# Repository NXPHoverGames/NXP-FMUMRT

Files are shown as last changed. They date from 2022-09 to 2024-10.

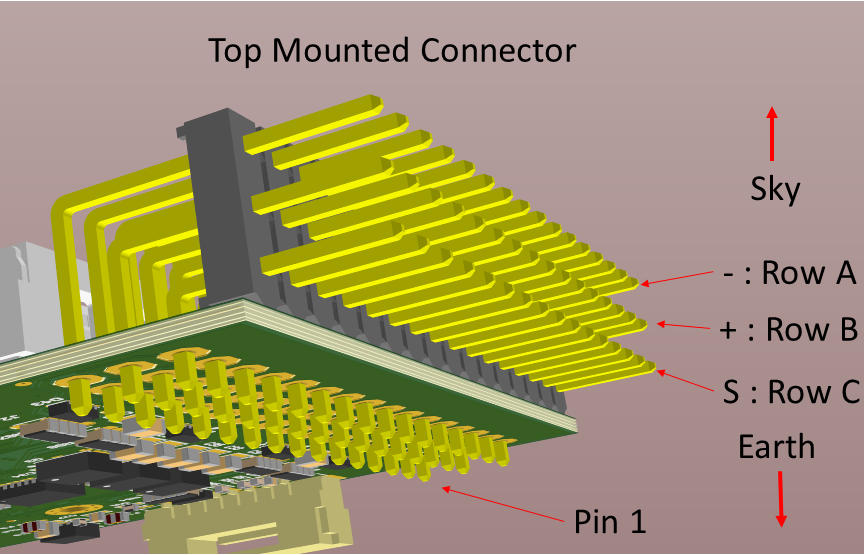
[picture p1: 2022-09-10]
RT-VxX_Carrier_Board/RC01/Project_fmuvxXbaseT1_RC01_20220511_1/3x16_Header.png

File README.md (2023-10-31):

# NXP-FMUMRT, MR-FMURT6, MR-VMU-RT117x
This is an open reference design for a Pixhawk V5X (i.MX RT1062) / V6X (i.MX RT117x) flight controller. 

Note1: For MR-FMURT6 based on NXP i.MX RT1062: This design is NOT being produced in volume, and we will produce MR-VMU-RT1176 using i.MX RT1176 MCU instead.
The RT1176 offers higher processing speed (Ghz) and additional UARTS as well as a dual core processor.
MR-FMURT6 It is still a valuable reference point for cost-optimzed design usign i.MX RT1062
Alternative software could also be used on this design such as Zephyr + Cognipilot.

Note2: MR-VMU-RT117x is being called a "VMU" or "Vehicle Management Unit" rather than "FMU" or "Flight Management Unit" since this is more inclusive 
of the many types of vehicles that can use a real time controller. 

Note3: The i.MX RT117x is currently contstrained on MR-VMU-RT117x by the Pixhawk Autopilot Bus (PAB) connector standard. 
The PAB standard was already revised to allow for extra PWM from the RT1176 and allows potential elimination of the IO co-processor that is on 
the VxX carrier board. Additionally there is a 3rd CAN port available.
(July/2023) - In the future look for a revised VxX7 carrier board which makes use of these new signals on the PAB.

Note4: Given the i.MX RT117x is currently contstrained on MR-VMU-RT117x, we will look in the future collaboration on a "chip down" design that takes advantage
of all the extra IP an peripherals such as the camera and vision pipeline that are currently unused on this chip.

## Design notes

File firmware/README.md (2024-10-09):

# Firmware for px4_fmu-v6xrt (i.MX RT117x)

**This info is aimed to be used for testers of the Pixhawk 6X-RT (Developer Edition)**

Hardware desccription on Manufacturers webpage - https://holybro.com/products/fmuv6x-rt-developer-edition
Documentation on PX4.io - https://docs.px4.io/main/en/flight_controller/pixhawk6x-rt.html

**IMPORTANT** if you are using the v6xrt FMUM on a development baseboard from NXP and like to use the T1 ethernet: 
Please make sure that you enable the T1 ethernet PHY - **TJA1103** - via **make px4_fmu-v6xrt menuconfig**. 
Ethernet PHY is in **Device Drivers** --> **Network Device/PHY Support** --> **Board PHY Selection (ETH0)** 

## Firmware sources
PX4 firmware for px4_fmu-v6xrt has been merged to PX4 main - https://github.com/PX4/PX4-Autopilot on Nov 15th 2023.
Please build from there.

## Issue reporting
Please report all issues found via https://github.com/PX4/PX4-Autopilot/issues/new/choose

## flashing the code
### with QGC
For flashing code with QGC stable release version v4.4.0 or later is needed  - https://docs.qgroundcontrol.com/master/en/qgc-user-guide/getting_started/download_and_install.html

### with PX4 developer toolchain based on own compiled code
1) Install PX4 developer toolchain according https://docs.px4.io/main/en/dev_setup/dev_env.html
2) Download PX4 Autopilot sourcecode - https://docs.px4.io/main/en/dev_setup/building_px4.html#download-the-px4-source-code
3) Move into PX4-Autopilot code directory
4) do **git pull --recurse-submodules**
5) optional: do **make distclean** if you had build already from this code directory before.
6) do **make px4_fmu-v6xrt_default upload** to build the PX4 FW image and flash via USB
7) connect Pixhawk v6X-RT via USB to flash the PX4 FW image

### updating the bootloader
For this a **SEGGER debug probe** HW is needed - https://www.segger.com/products/debug-trace-probes/
As well as the **SEGGER J-Link** SW - https://www.segger.com/downloads/jlink/
And the **Pixhawk Debug Adapter** - https://holybro.com/collections/flight-controller-accessories/products/pixhawk-debug-adapter

1) Move into PX4-Autopilot code directory with checked out pr-px4_fmu-v6xrt (see instruction above)
2) do **git pull --recurse-submodules**
3) do **make distclean**
4) do **make px4_fmu-v6xrt_bootloader** to build the PX4 bootloader
5) Connect the holybro pixhawk debug adapter, with SEGGER debug probe connected, to Pixhawk 6X-RT
6) Power the Pixhawk 6X-RT either via USB or POWERx connector.
7) Launch JlinkExe
8) Type connect
9) Select SWD and target is MIMXRT1176XXXA_M7
10) type reset and halt
11) Type loadbin /path/to/firmware/px4_fmu-v6xrt_bootloader.bin 0x30000000              # needed only in case of bootloader to be flashed
12) type reset and go

## Precompiled PX4 FW images

**IMPORTANT:** Support for px4_fmu-v6xrt has been merged to PX4 main on 15th of Nov 2023. Therefore we no longer provide precompiled images.
Please build the bootloader and PX4 FW according instruction above.

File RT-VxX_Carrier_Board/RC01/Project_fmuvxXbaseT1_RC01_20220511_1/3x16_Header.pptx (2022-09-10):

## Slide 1

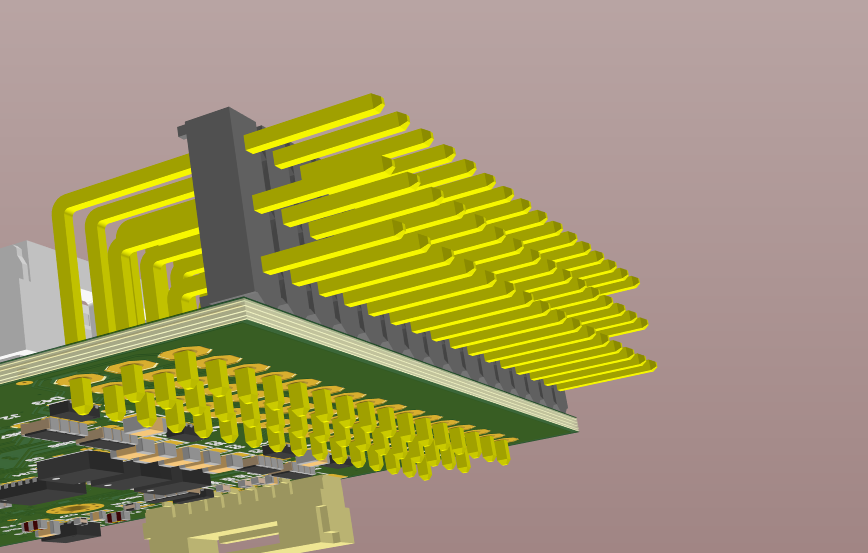
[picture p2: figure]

Top Mounted Connector

Sky

- : Row A

+ : Row B

S : Row C

Earth

Pin 1

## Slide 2

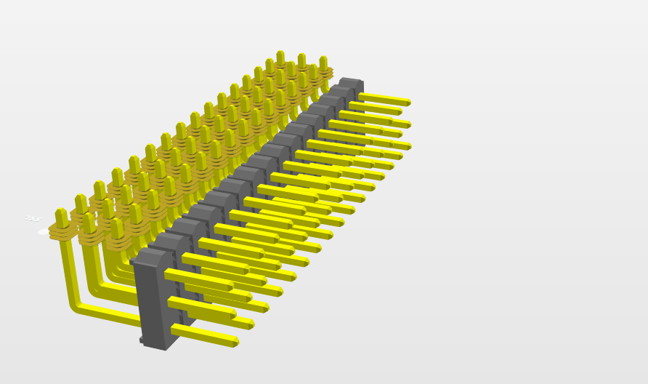
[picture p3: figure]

Bottom Mounted Connector

- : Row C

Pin 1

+ : Row B

S : Row A

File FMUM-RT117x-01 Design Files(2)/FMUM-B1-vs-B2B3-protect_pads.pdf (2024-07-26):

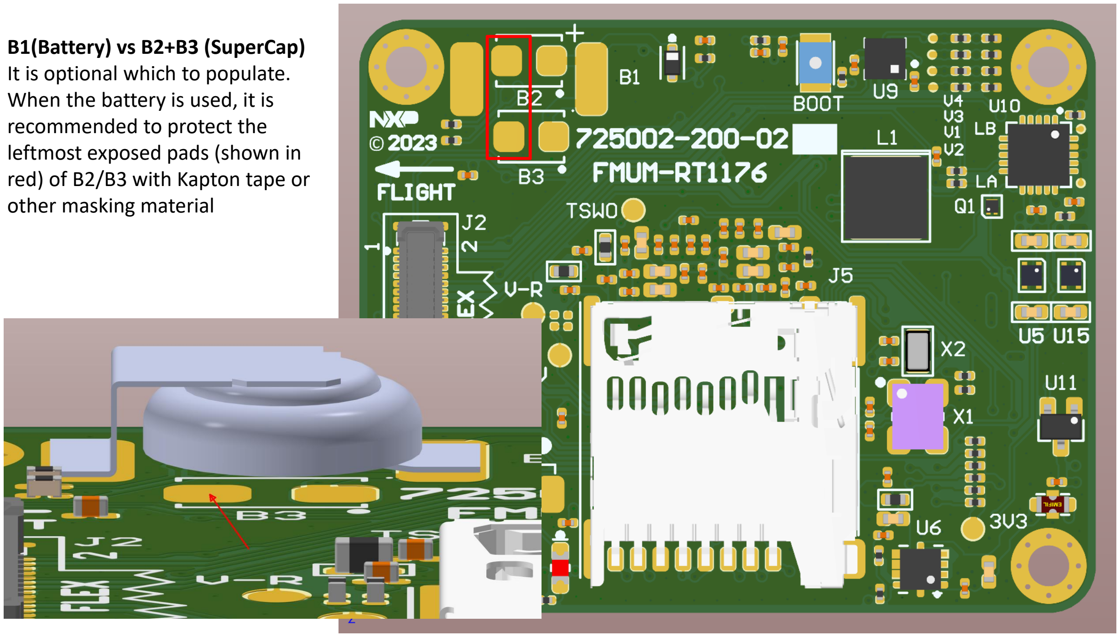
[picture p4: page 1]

B1(Battery) vs B2+B3 (SuperCap) It is optional which to populate. When the battery is used, it is recommended to protect the leftmost exposed pads (shown in red) of B2/B3 with Kapton tape or other masking material

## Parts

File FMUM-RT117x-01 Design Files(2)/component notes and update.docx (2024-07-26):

26/07/2024

Notes on components or FMUMRT1176 and Vxx-T1
1) MAX803SQ263T1G : As a replacement for MAX803SQ263T1G, I would suggest to use MIC803-26D3VC3 instead. This has the same specifications as the original. The suggested part is almost the same, but has a different threshold voltage.
https://www.digikey.nl/en/products/detail/microchip-technology/MIC803-26D3VC3-TR/2566974

2) 3225SMD-24.000MHZ crystal has already been replaced in the last update by Kyocera CX3225SB24000D0FLJCC.
https://www.digikey.nl/en/products/detail/kyocera-avx/CX3225SB24000D0FLJCC/6123307

# 3) The BMP388 barometer on the FMUM has been replaced already by BMP390 in the latest update. https://www.digikey.nl/en/products/detail/bosch-sensortec/BMP390/16164575 4) B1, MS621R II27E – Lithium battery may be difficult to source. The design allows for supercap alternative 2x CPH3225A

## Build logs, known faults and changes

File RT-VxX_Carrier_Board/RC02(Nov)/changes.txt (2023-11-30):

11/30/2023 iafg

-	Resistor values changed which give the id of the board
-	Corrected the reverse pinning on the DSM connector
-	Physically Moved the NFC cable connector that was blocking the SDCARD
- Re-Connected “loose” signals for the GPS arming and led. (the nets got accidentally disconnected when the IO processor was removed)

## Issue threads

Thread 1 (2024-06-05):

No internal MAG sensor?

napdynamite, 2024-06-05:
Hi,

I have been trying to find the internal MAG sensor on FMURT6 BOM but I guess this design does not have internal MAG sensor. Or is the design pending?

igalloway, 2024-06-05:
This is a PX4 FMUM (module) design. There is an IMU module that attaches on a flex cable. Also there is/may be one on a carrier board.
I suggest you look at the RT1176 designs instead. We are manufacturing that and it is validation testing.
There will also be a simpler RT1060 design available shortly.
You may email me directly for more detailed discussion about your needs:
iain.galloway@nxp.com

Closed 2024-07-26.

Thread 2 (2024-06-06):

FMUM-RT117X SuperCap

napdynamite, 2024-06-06:
Hi,

There's a supercap used in the FMUM for power backup. In my understanding, this is used in the event when 3V3 VDD is no longer there and supercap may provide power for sometime, right?

This supercap is no longer available and is obsolete. What would happen if this supercap is eliminated altogether? Atleast for lab/ground verifications where we make sure FMU_VDD is constant and good.

igalloway, 2024-06-06:
We are aware that this supercap is no longer available officially. (there is stock in the market)
We have adjusted the production design to include a lower capacity alternative supercap that is available
We also allowed for a primary small lithium cell on the carrier board.

The actual usage and need is up to the application.
the primary goal is to keep a real time clock and some other log data available in volatile memory when there may be a shutdown/battery swap or other event.
Typically software will regain the Real time clock from something like a GPS. But it could of course come from another source.

My *personal opinion* is that a primary lithium cell on the carrier board is the lowest cost and best performing option in many cases.

Regards
-iain

Iain Galloway
NXP Semiconductors
Mobile Robotics Domain Lead, Drones and Rovers
System Innovations CTO R&D
TX30/MS:OE320, Office F3-149
6501 W William Cannon Dr
Austin, TX, USA 78735

978-494-4246

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

napdynamite, 2024-06-07:
Any luck on this one?

igalloway, 2024-06-07:
Attached is the last IMU sent for schematic update.
I don't have the resulting file back yet.

Please read the notes carefully.
As mentioned there needs to be a small voltage regulator attached if one of the components is used.

Otherwise these are a copy of the PX4 IMU reference design.

Iain Galloway
NXP Semiconductors
Mobile Robotics Program Lead
6501 W William Cannon Drive
Austin, TX, USA, 78735
978-494-4246

________________________________
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

napdynamite, 2024-06-07:
I am talking about the lithium cell for RTB BAT that is used in carrier board as you have mentioned.

> We are aware that this supercap is no longer available officially. (there is stock in the market) We have adjusted the production design to include a lower capacity alternative supercap that is available We also allowed for a primary small lithium cell on the carrier board. The actual usage and need is up to the application. the primary goal is to keep a real time clock and some other log data available in volatile memory when there may be a shutdown/battery swap or other event. Typically software will regain the Real time clock from something like a GPS. But it could of course come from another source. My *personal opinion* is that a primary lithium cell on the carrier board is the lowest cost and best performing option in many cases. Regards -iain Iain Galloway NXP Semiconductors Mobile Robotics Domain Lead, Drones and Rovers System Innovations CTO R&D TX30/MS:OE320, Office F3-149 6501 W William Cannon Dr Austin, TX, USA 78735 978-494-4246 From: Anas Bin Iftikhar ***@***.***> Sent: Thursday, June 6, 2024 3:34 AM To: NXPHoverGames/NXP-FMUMRT ***@***.***> Cc: Subscribed ***@***.***> Subject: [EXT] [NXPHoverGames/NXP-FMUMRT] FMUM-RT117X SuperCap (Issue #2) Caution: This is an external email. Please take care when clicking links or opening attachments. When in doubt, report the message using the 'Report this email' button Hi, There's a supercap used in the FMUM for power backup. In my understanding, this is used in the event when 3V3 VDD is no longer there and supercap may provide power for sometime, right? This supercap is no longer available and is obsolete. What would happen if this supercap is eliminated altogether? Atleast for lab/ground verifications where we make sure FMU_VDD is constant and good. - Reply to this email directly, view it on GitHub<#2>, or unsubscribe<https://github.com/notifications/unsubscribe-auth/ACQFV7SIMDDTR7HM7YEXWJTZGANGJAVCNFSM6AAAAABI4HVBOWVHI2DSMVQWIX3LMV43ASLTON2WKOZSGMZTONRWGI2TAOI>. You are receiving this because you are subscribed to this thread.Message ID: ***@***.******@***.***>>

igalloway, 2024-06-07:
Ok will need to be Monday.
Attached is a clip of how it was added to the schematic.
It's under review still.

Iain Galloway
NXP Semiconductors
Mobile Robotics Program Lead
6501 W William Cannon Drive
Austin, TX, USA, 78735
978-494-4246
________________________________
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

Taskeenriaz, 2024-06-20:
In the reference file we have BMI088, so there is a note that INT2 and INT4 are not connected as per data sheet but , in datasheet it uses, also do its specific role of accelerometer and gyro so do let me know that if we are using so what will be the  consequences.

igalloway, 2024-07-26:
Latest design files are updated and in the directory here:
https://github.com/NXPHoverGames/NXP-FMUMRT/tree/main/FMUM-RT117x-01%20Design%20Files(2)

igalloway, 2024-07-26:
Note the IMU on flex that attaches to the FMUM is not included in the design files here yet. This is identical to the Pixhawk reference and that can be used. We will eventually duplicate it here, but that is pending.

Closed 2024-07-26.

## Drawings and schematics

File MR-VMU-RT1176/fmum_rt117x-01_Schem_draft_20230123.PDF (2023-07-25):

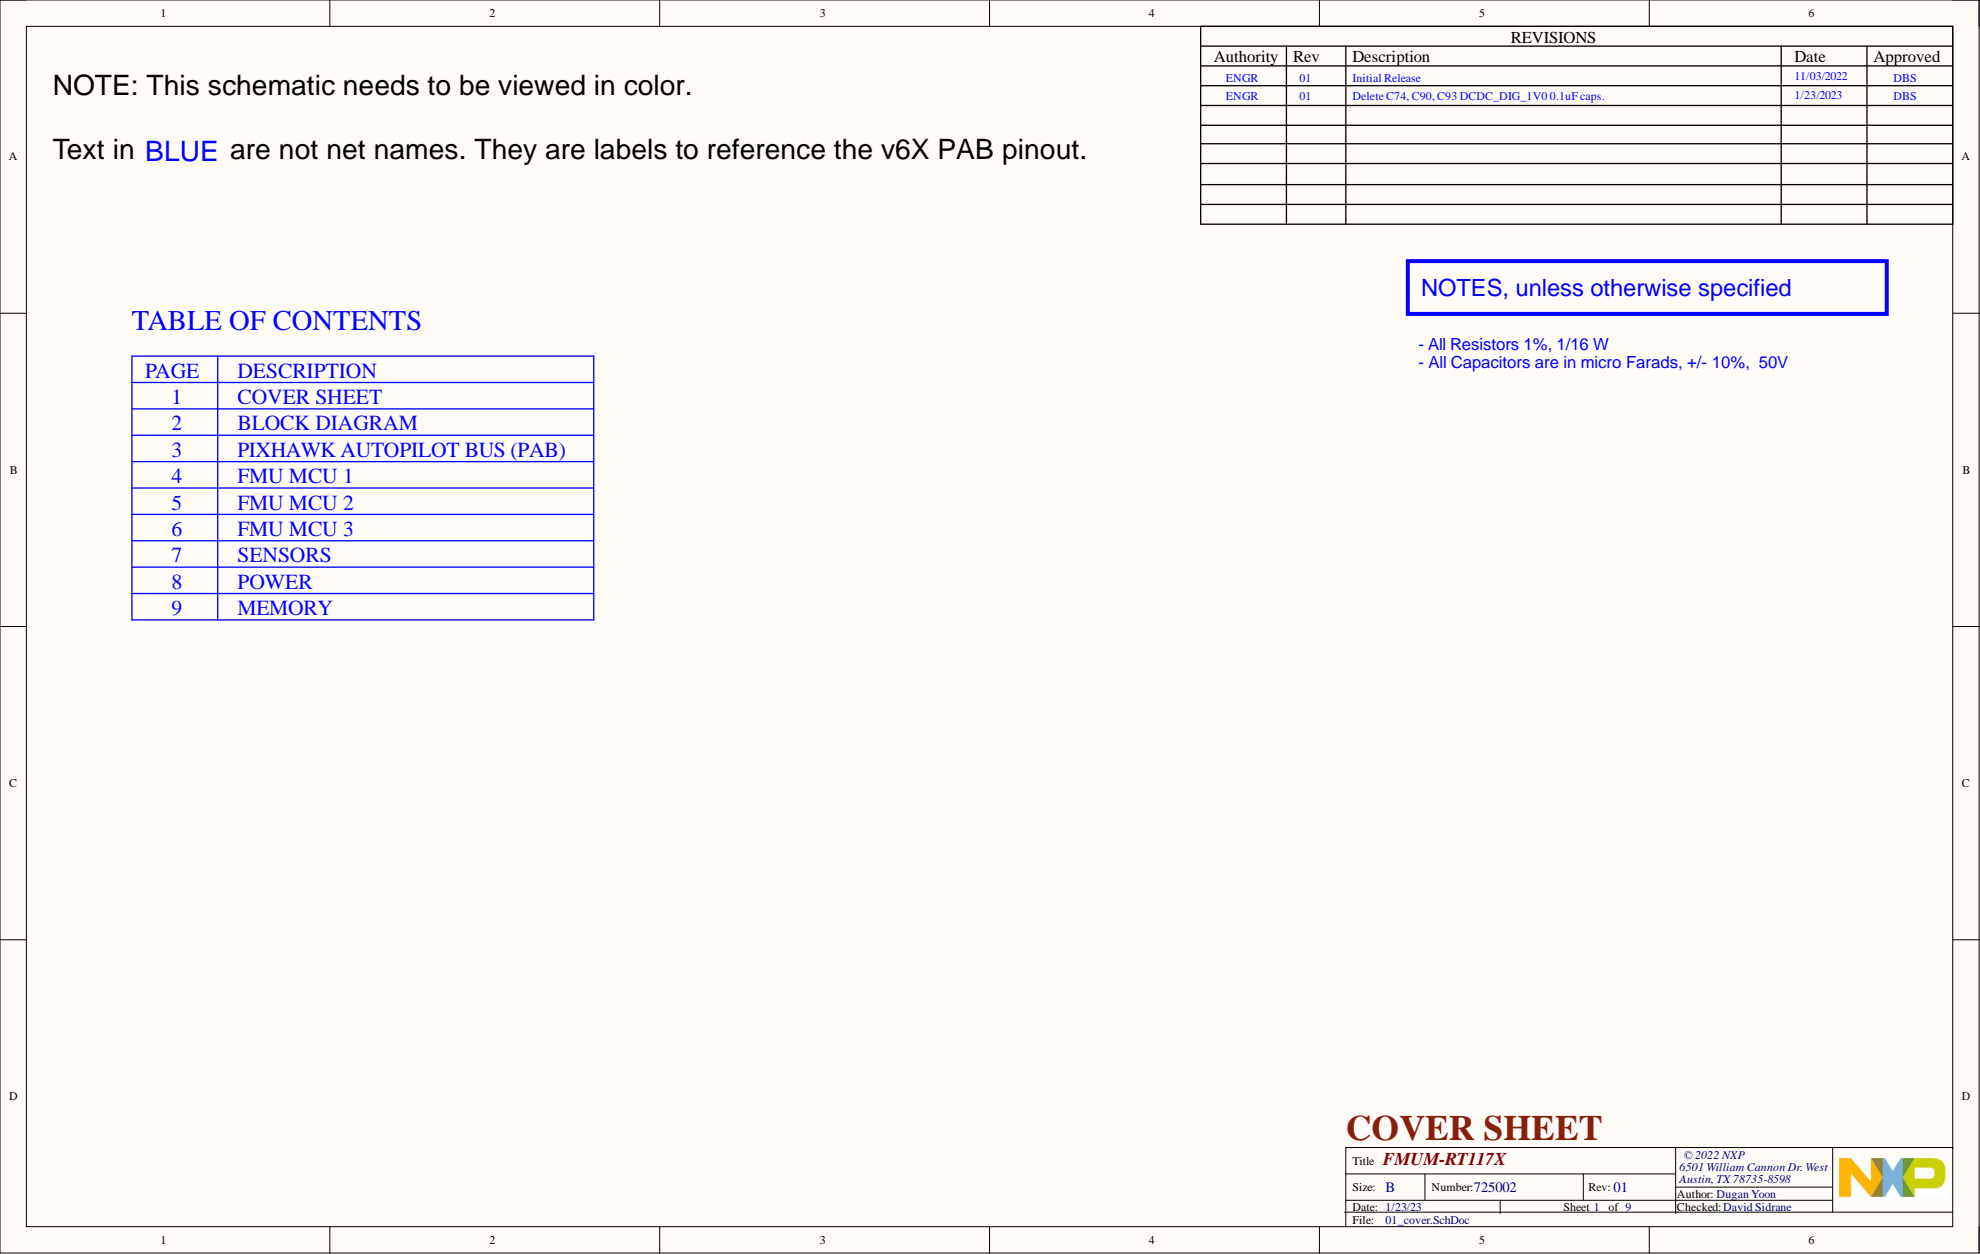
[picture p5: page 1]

Authority | Rev | Description | Date | Approved

NOTE: This schematic needs to be viewed in color.

ENGR | 01 | Initial Release | 11/03/2022 | DBS
ENGR | 01 | Delete C74, C90, C93 DCDC_DIG_1V0 0.1uF caps. | 1/23/2023 | DBS

NOTES, unless otherwise specified

- All Resistors 1%, 1/16 W
- All Capacitors are in micro Farads, +/- 10%, 50V

PAGE | DESCRIPTION
1 | COVER SHEET
2 | BLOCK DIAGRAM
3 | PIXHAWK AUTOPILOT BUS (PAB)
4 | FMU MCU 1
5 | FMU MCU 2
6 | FMU MCU 3
7 | SENSORS
8 | POWER
9 | MEMORY

© 2022 NXP
6501 William Cannon Dr. West
Austin, TX 78735-8598

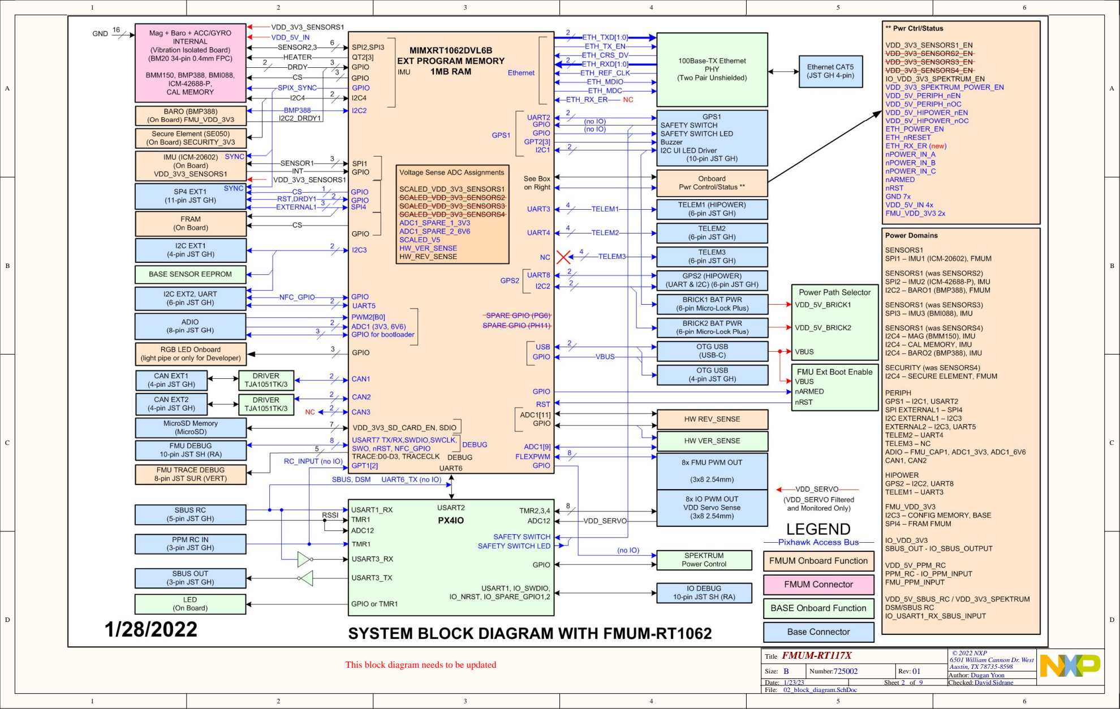
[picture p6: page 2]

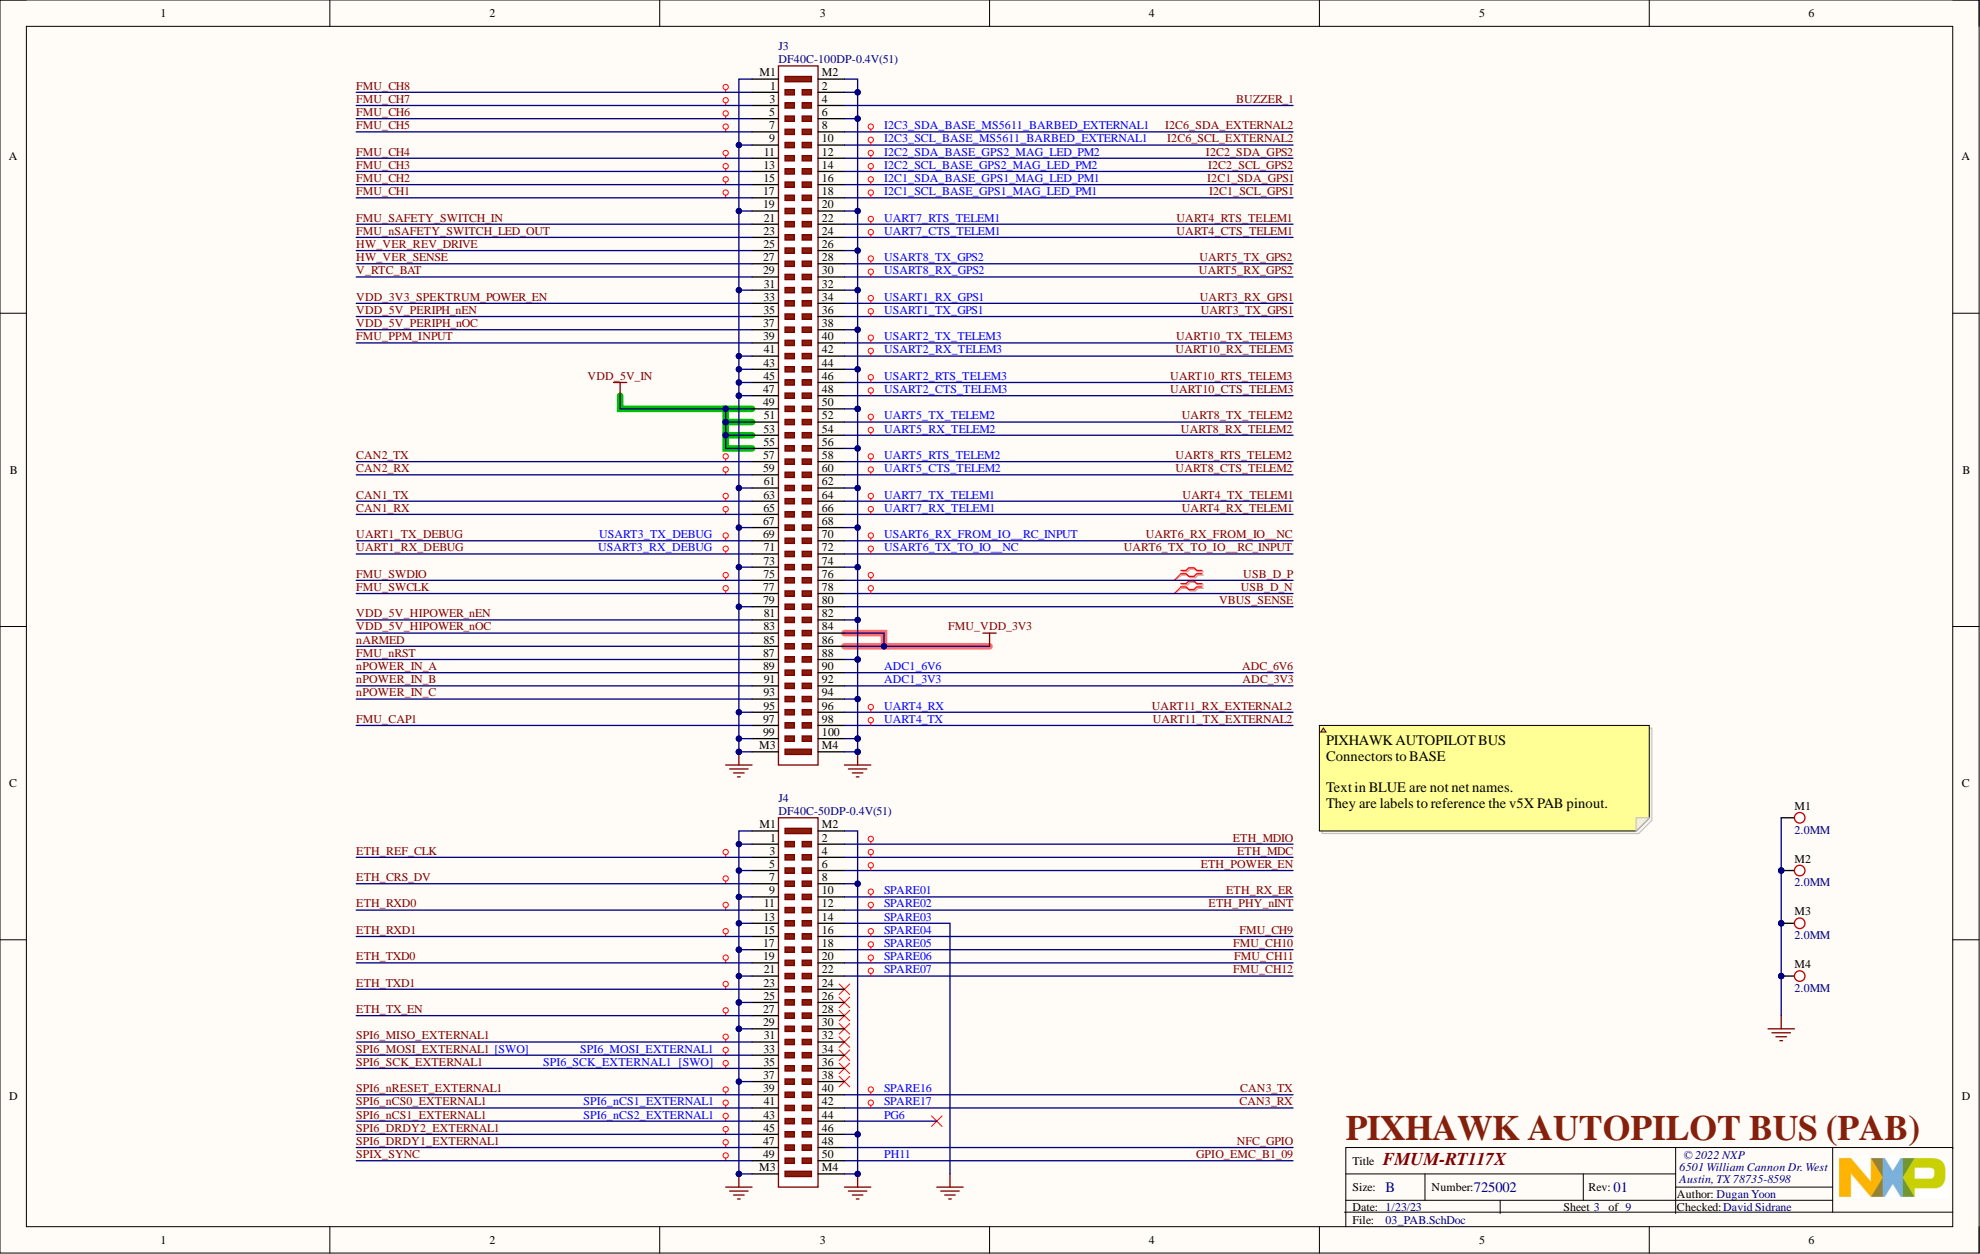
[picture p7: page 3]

5 1 | 5 2 5 4 5 6
5 3
5 5
5 7 5 9 6 1 | | 5 8 6 0 6 2

PIXHAWK AUTOPILOT BUS (PAB)

Size : B | N umb er | Rev

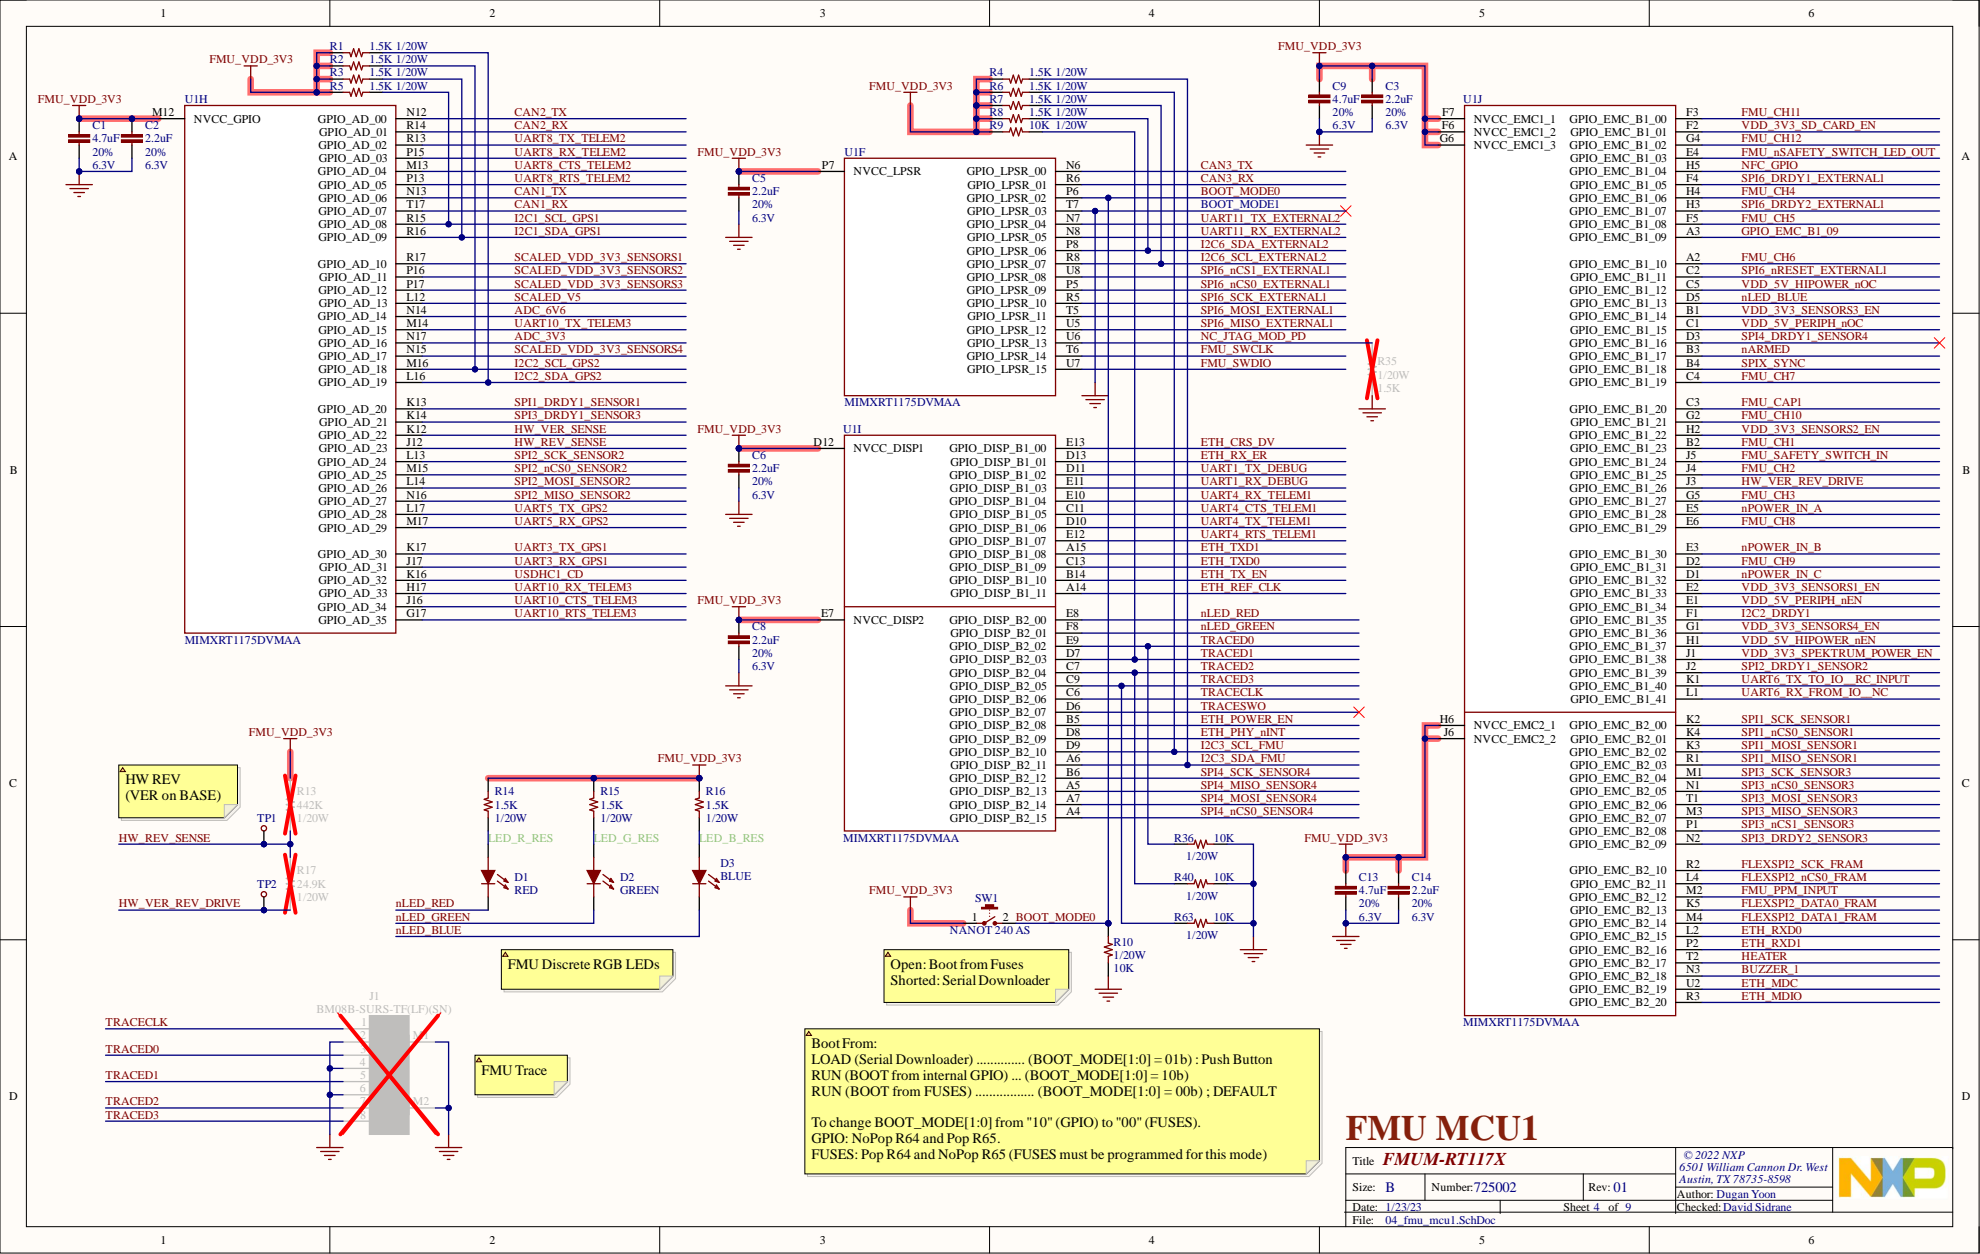
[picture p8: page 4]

N 7 | | U A RT 1 1 _ T X _ E X T E RN A L2
N 8 | | U A RT 1 1 _RX _ E X T E RN A L2

7 | R8 | | | I2C6 _SCL _ E X T E RN A L2

8 9 0 1 2 3 4 5 | U 8 | | | SPI6 _ nCS1 _ E X T E RN A L 1

P5 | | | SPI6 _ nCS0 _ E X T E RN A L 1

R5 | | | SPI6 _SCK _ E X T E RN A L 1
T 5 | | | SPI6 _MOSI_ E X T E RN A L 1

U 5 | | | SPI6 _MISO _ E X T E RN A L 1

U 6 | | | NC_ J TA G_MO D _PD
T 6 | | | FMU _SWCL K

U 7 | | | FMU _SW D I O

N VCC_ DIS P 1 GPIO _ DISP_B1 _ 0 GPIO _ DISP_B1 _ 0 GPIO _ DISP_B1 _ 0 GPIO _ DISP_B1 _ 0 GPIO _ DISP_B1 _ 0 GPIO _ DISP_B1 _ 0 GPIO _ DISP_B1 _ 0 GPIO _ DISP_B1 _ 0 GPIO _ DISP_B1 _ 0 GPIO _ DISP_B1 _ 0 GPIO _ DISP_B1 _ 1 GPIO _ DISP_B1 _ 1 | 0 1 2 3 4 5 6 7 8 9 0 1

E T H _CRS _D V

D 1 1 | | U A RT 1 _ T X _ D E B U G
E 1 1 | | U A RT 1 _RX _ D E B U G

E 1 0 | | U A RT 4 _RX _ T E LE M 1
C1 1 | | U A RT 4 _CTS_ T E LE M 1
D 1 0 | | U A RT 4 _ T X _ T E LE M 1
E 1 2 | | U A RT 4 _ RTS_ T E LE M 1

A 1 5 | | E T H _T X D 1
C1 3 | | E T H _T X D 0
B1 4 | | E T H _ T X_E N

A 1 4 | | E T H _REF_ C LK

GPIO _ DISP_B2 _ 1 GPIO _ DISP_B2 _ 1 | 3 4 5

LOAD (S
RUN (BOOT from intern
RUN (BOOT from

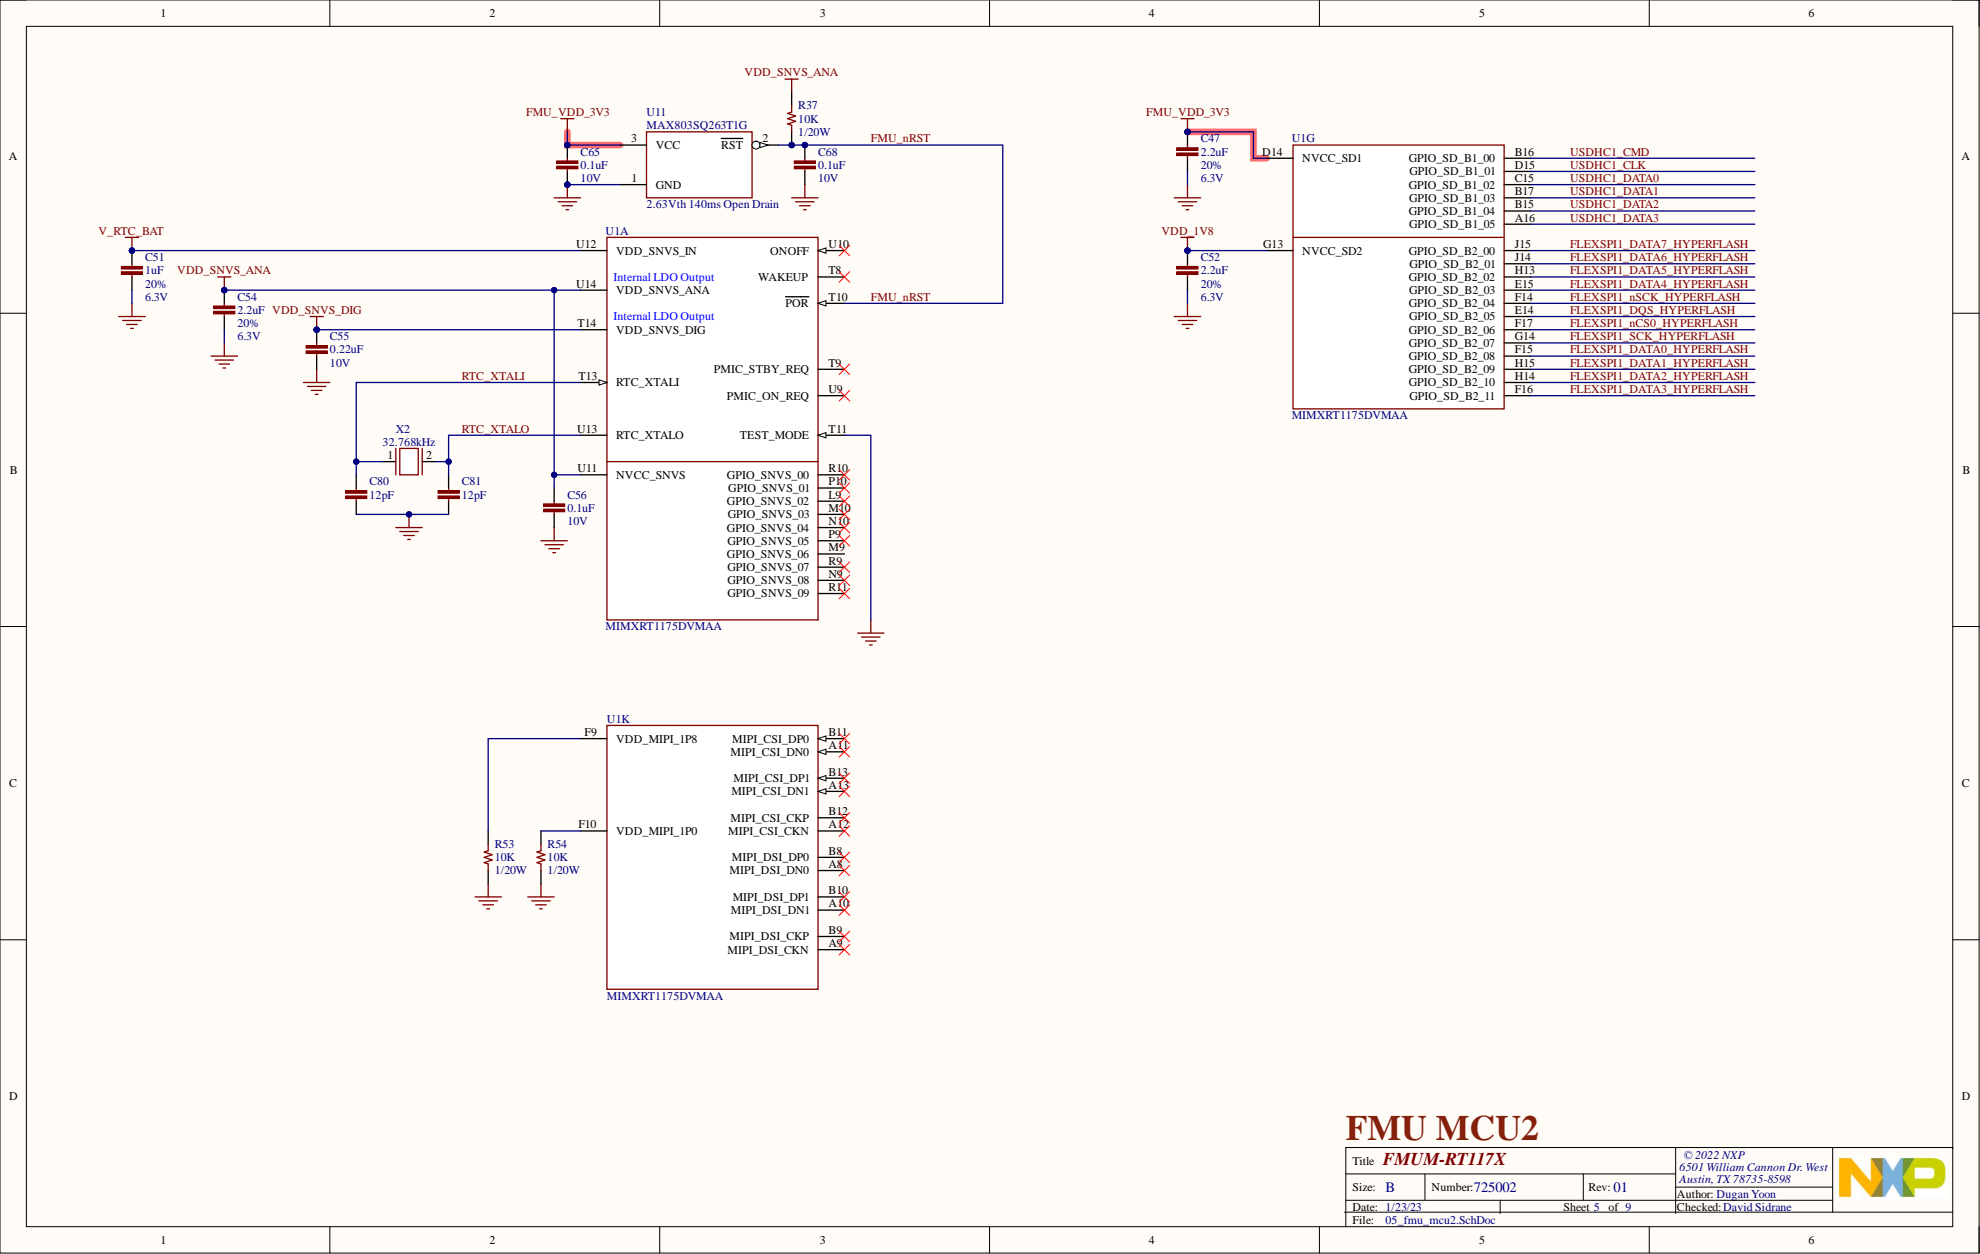
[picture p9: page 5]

X 2 RTC_ X TA LO | U | 1 3

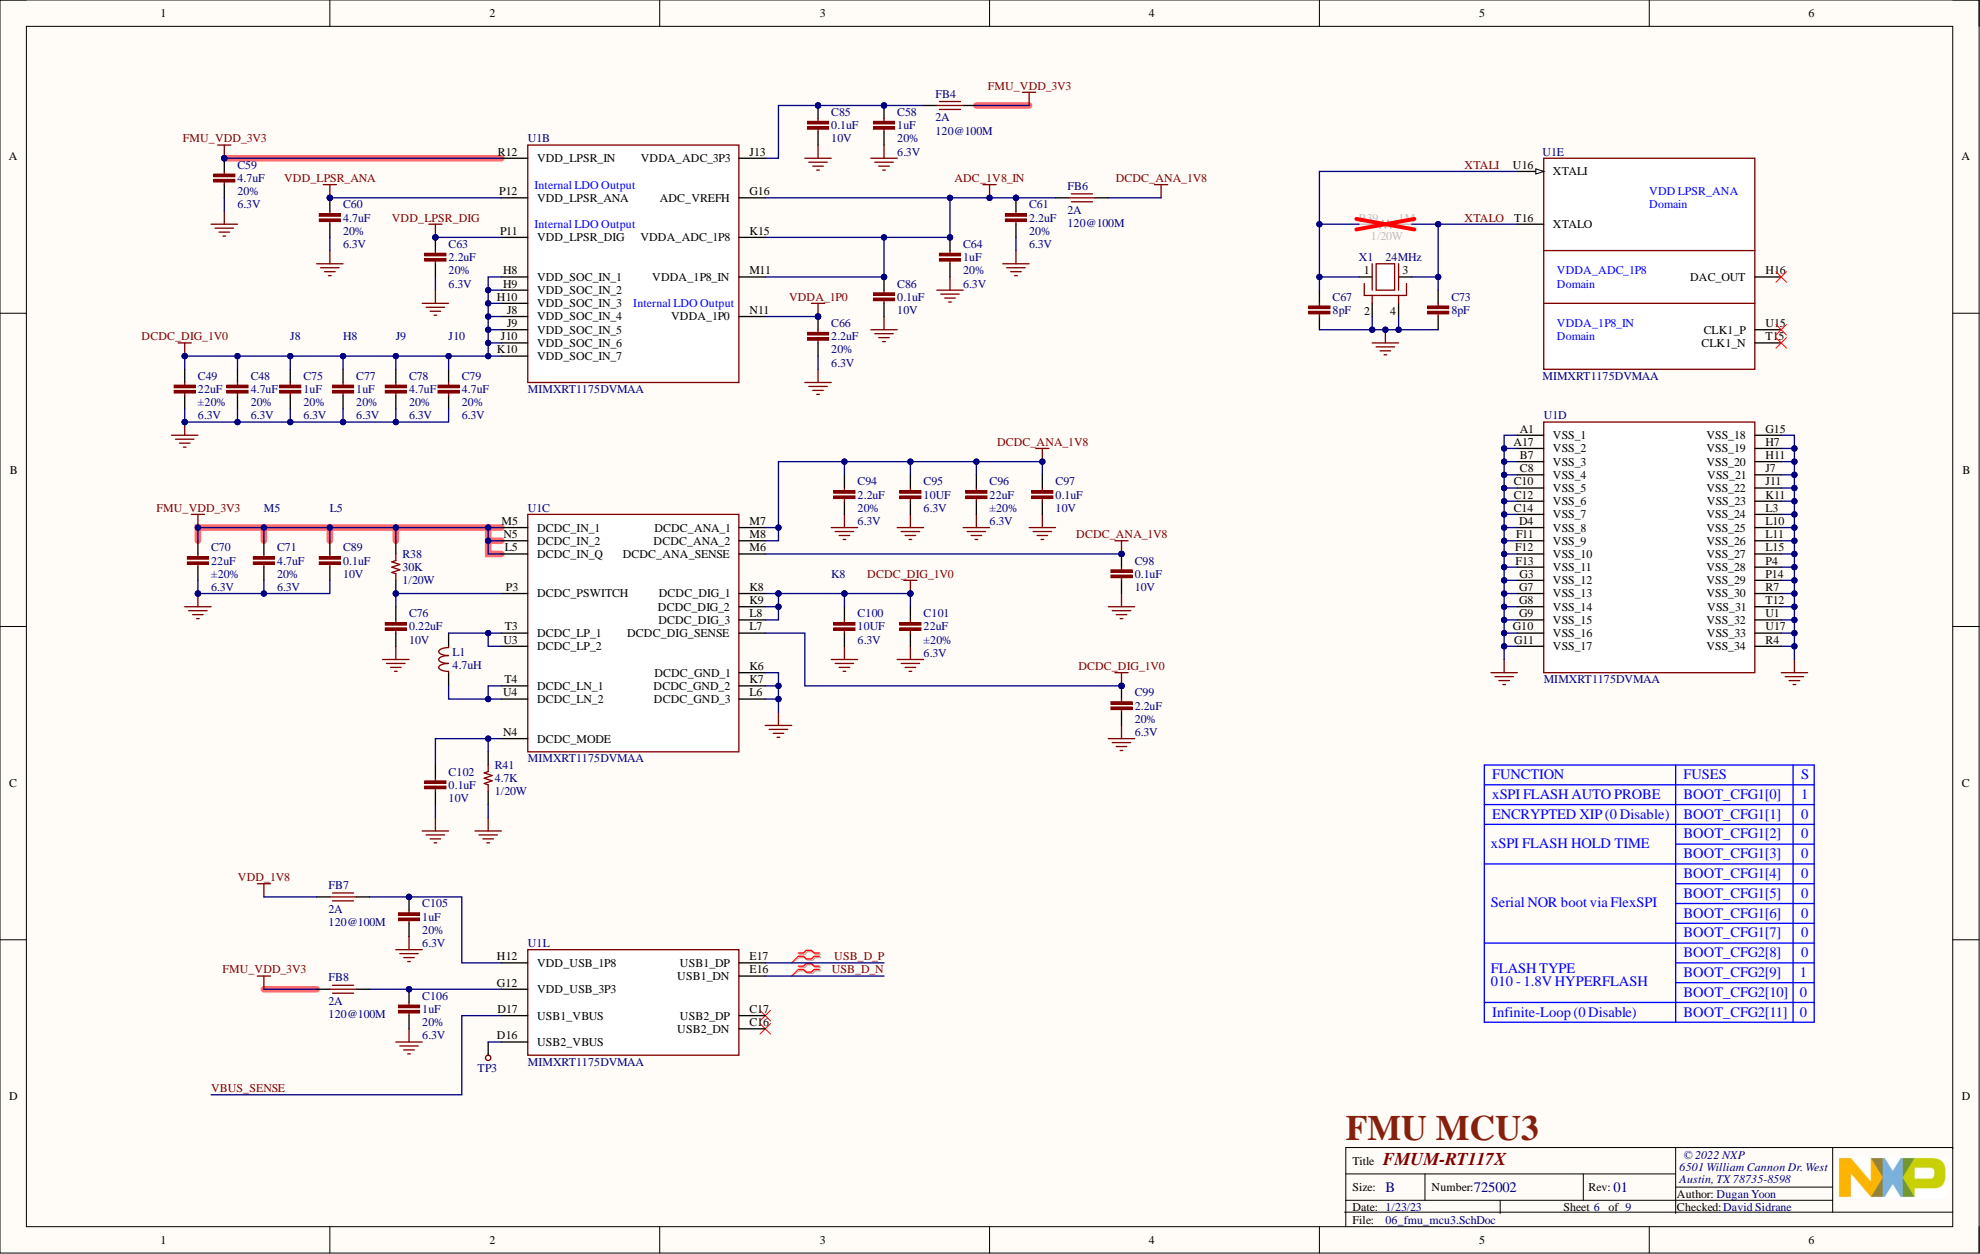
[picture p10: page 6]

R3 9 1 M X TA LO T | 1 6
1 W X 1 4MH | z

K 7
L 6

FUNCT I O N | FUSES | S
x S PI FLASH AUTO PROBE | BOOT_CF G 1 [ 0 ] | 1
ENCRYPTED XIP (0 Disa ble ) | BOOT_CF G 1 [ 1 ]
x S PI FLASH HOLD TIM E | BOOT_CF G 1 [ 2 ]

S erial NOR b o ot via Fle x S P I | BOOT_CF G 1 [ 4 ] | 10000000000

BOOT_CF G 1 [ 3 ]

BOOT_CF G 1 [ 5 ]
BOOT_CF G 1 [ 6 ]
BOOT_CF G 1 [ 7 ]

FLASH TYP E 0 1 0 -1.8 V HYPERFLAS H | BOOT_CF G 2 [ 8 ]

BOOT_CF G 2 [ 1 0 ]

Infinite-Lo o p (0 Disa b l e ) | BOOT_CF G 2 [ 1 1 ]

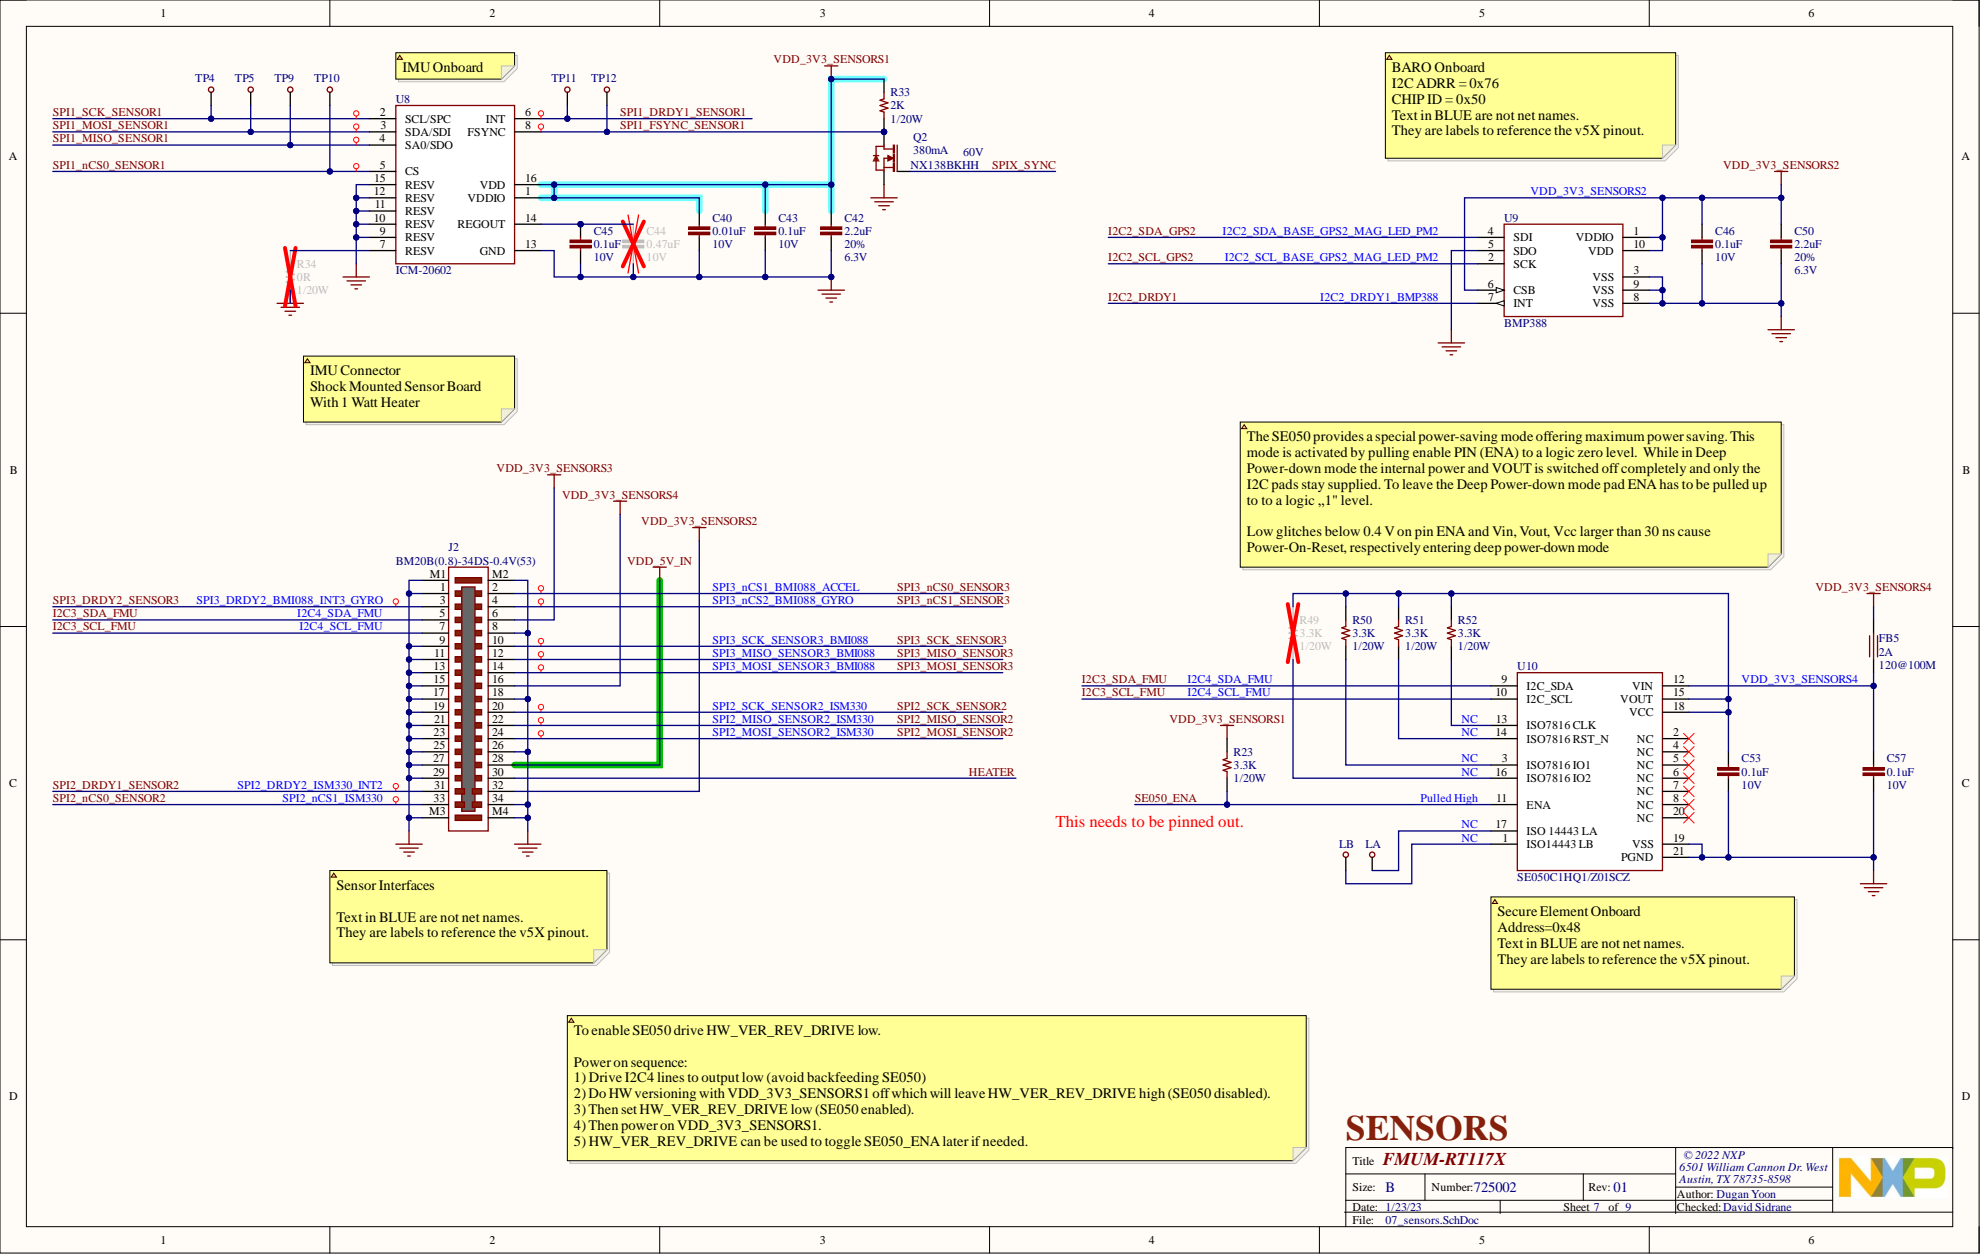
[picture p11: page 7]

BARO Onboard
I2C ADRR = 0x76
CHIP ID = 0x50
Text in BLUE are not net names.
They are labels to reference the v5X pinout.

IMU Connector
Shock Mounted Sensor Board
With 1 Watt Heater

The SE050 provides a special power-saving mode offering maximum power saving. This
mode is activated by pulling enable PIN (ENA) to a logic zero level. While in Deep
Power-down mode the internal power and VOUT is switched off completely and only the
I2C pads stay supplied. To leave the Deep Power-down mode pad ENA has to be pulled up
to to a logic „1" level.

Low glitches below 0.4 V on pin ENA and Vin, Vout, Vcc larger than 30 ns cause
Power-On-Reset, respectively entering deep power-down mode

This needs to be pinned out.

Secure Element Onboard
Address=0x48

To enable SE050 drive HW_VER_REV_DRIVE low.

Power on sequence:
1) Drive I2C4 lines to output low (avoid backfeeding SE050)
2) Do HWversioning with VDD_3V3_SENSORS1 off which will leave HW_VER_REV_DRIVE high (SE050 disabled).
3) Then set HW_VER_REV_DRIVE low (SE050 enabled).
4) Then power on VDD_3V3_SENSORS1.
5) HW_VER_REV_DRIVE can be used to toggle SE050_ENA later if needed.

6501 William Cannon Dr. West
Austin, TX 78735-8598

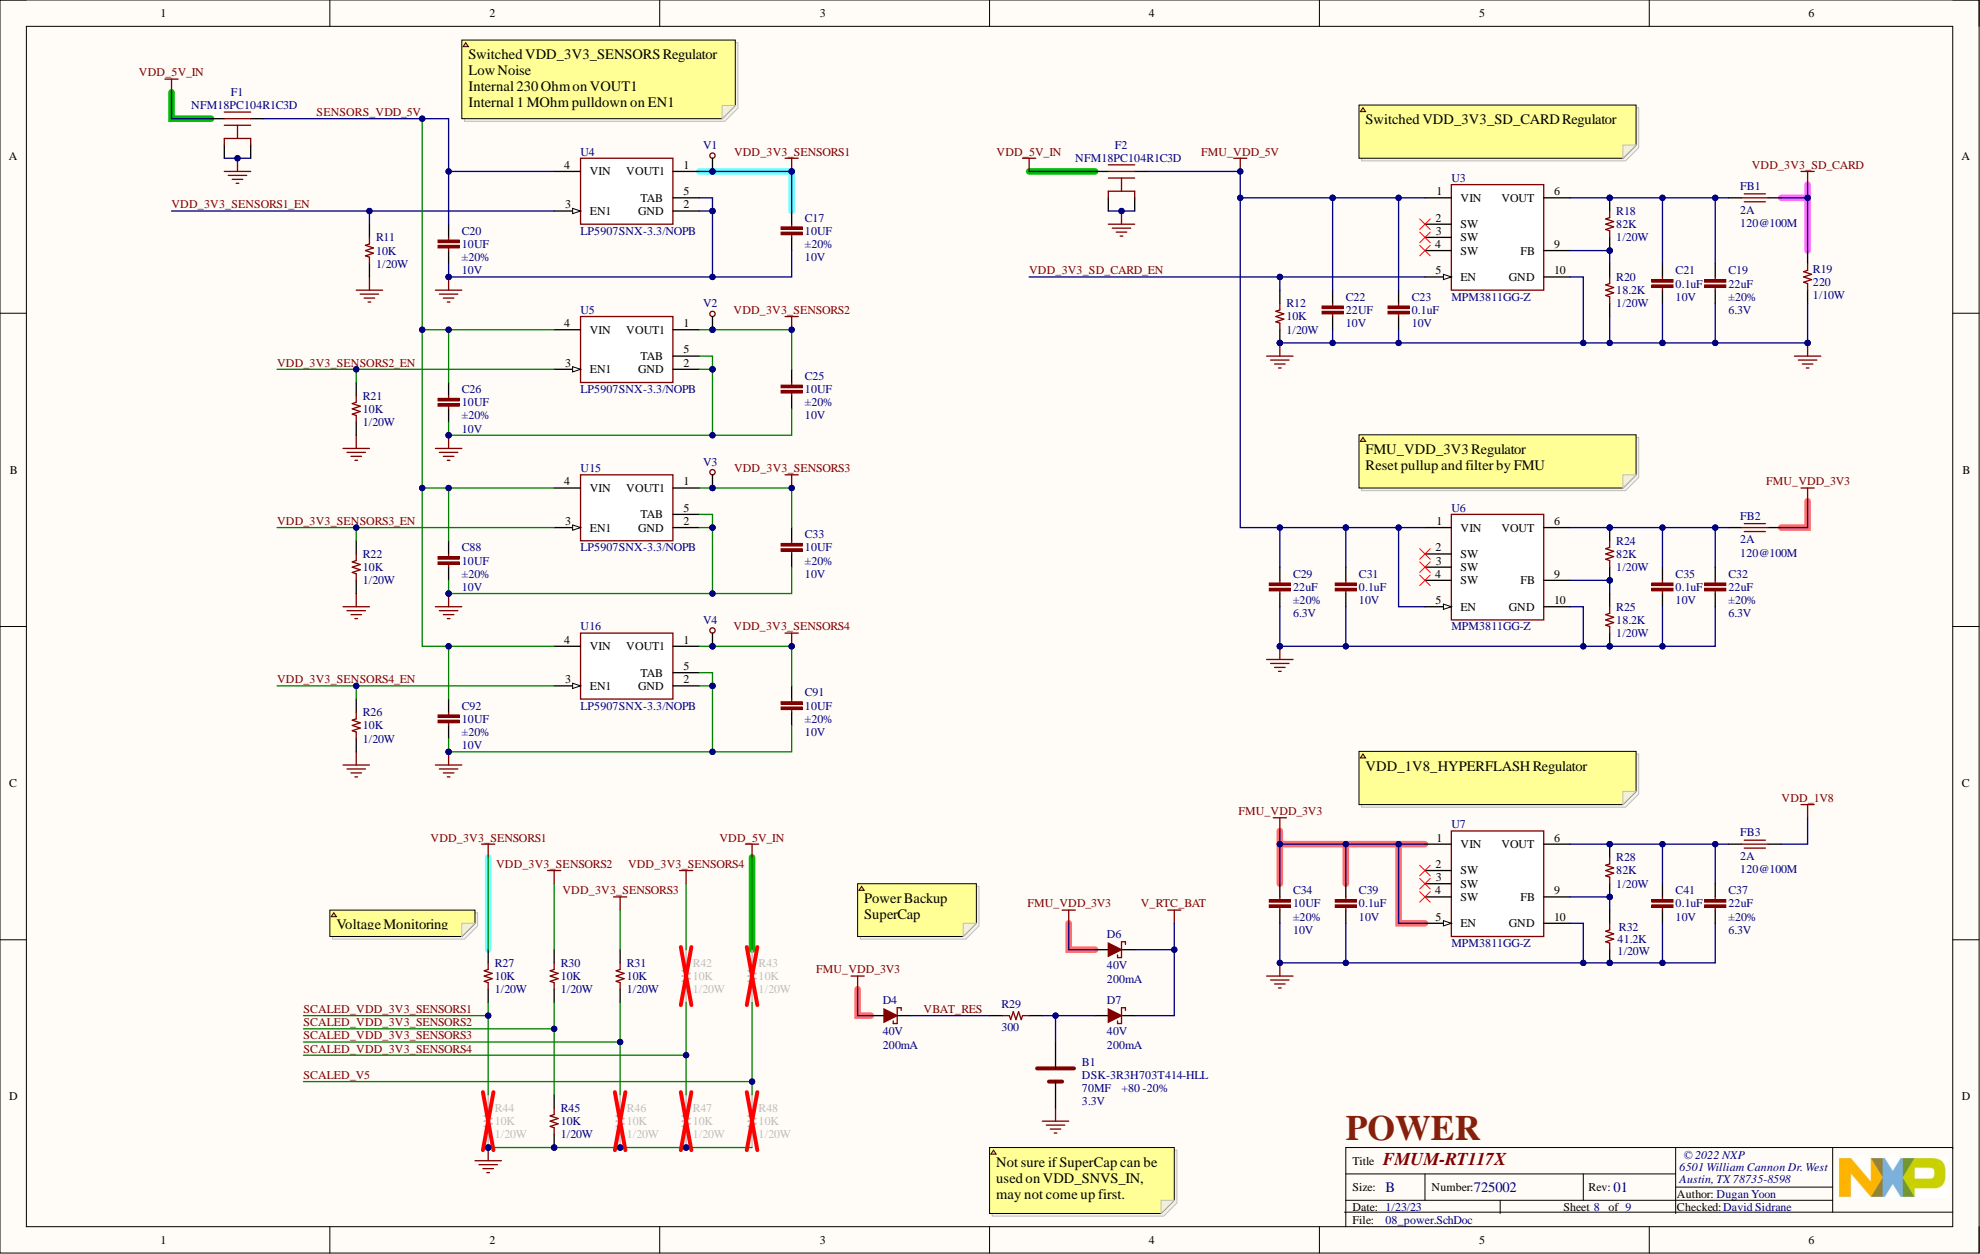
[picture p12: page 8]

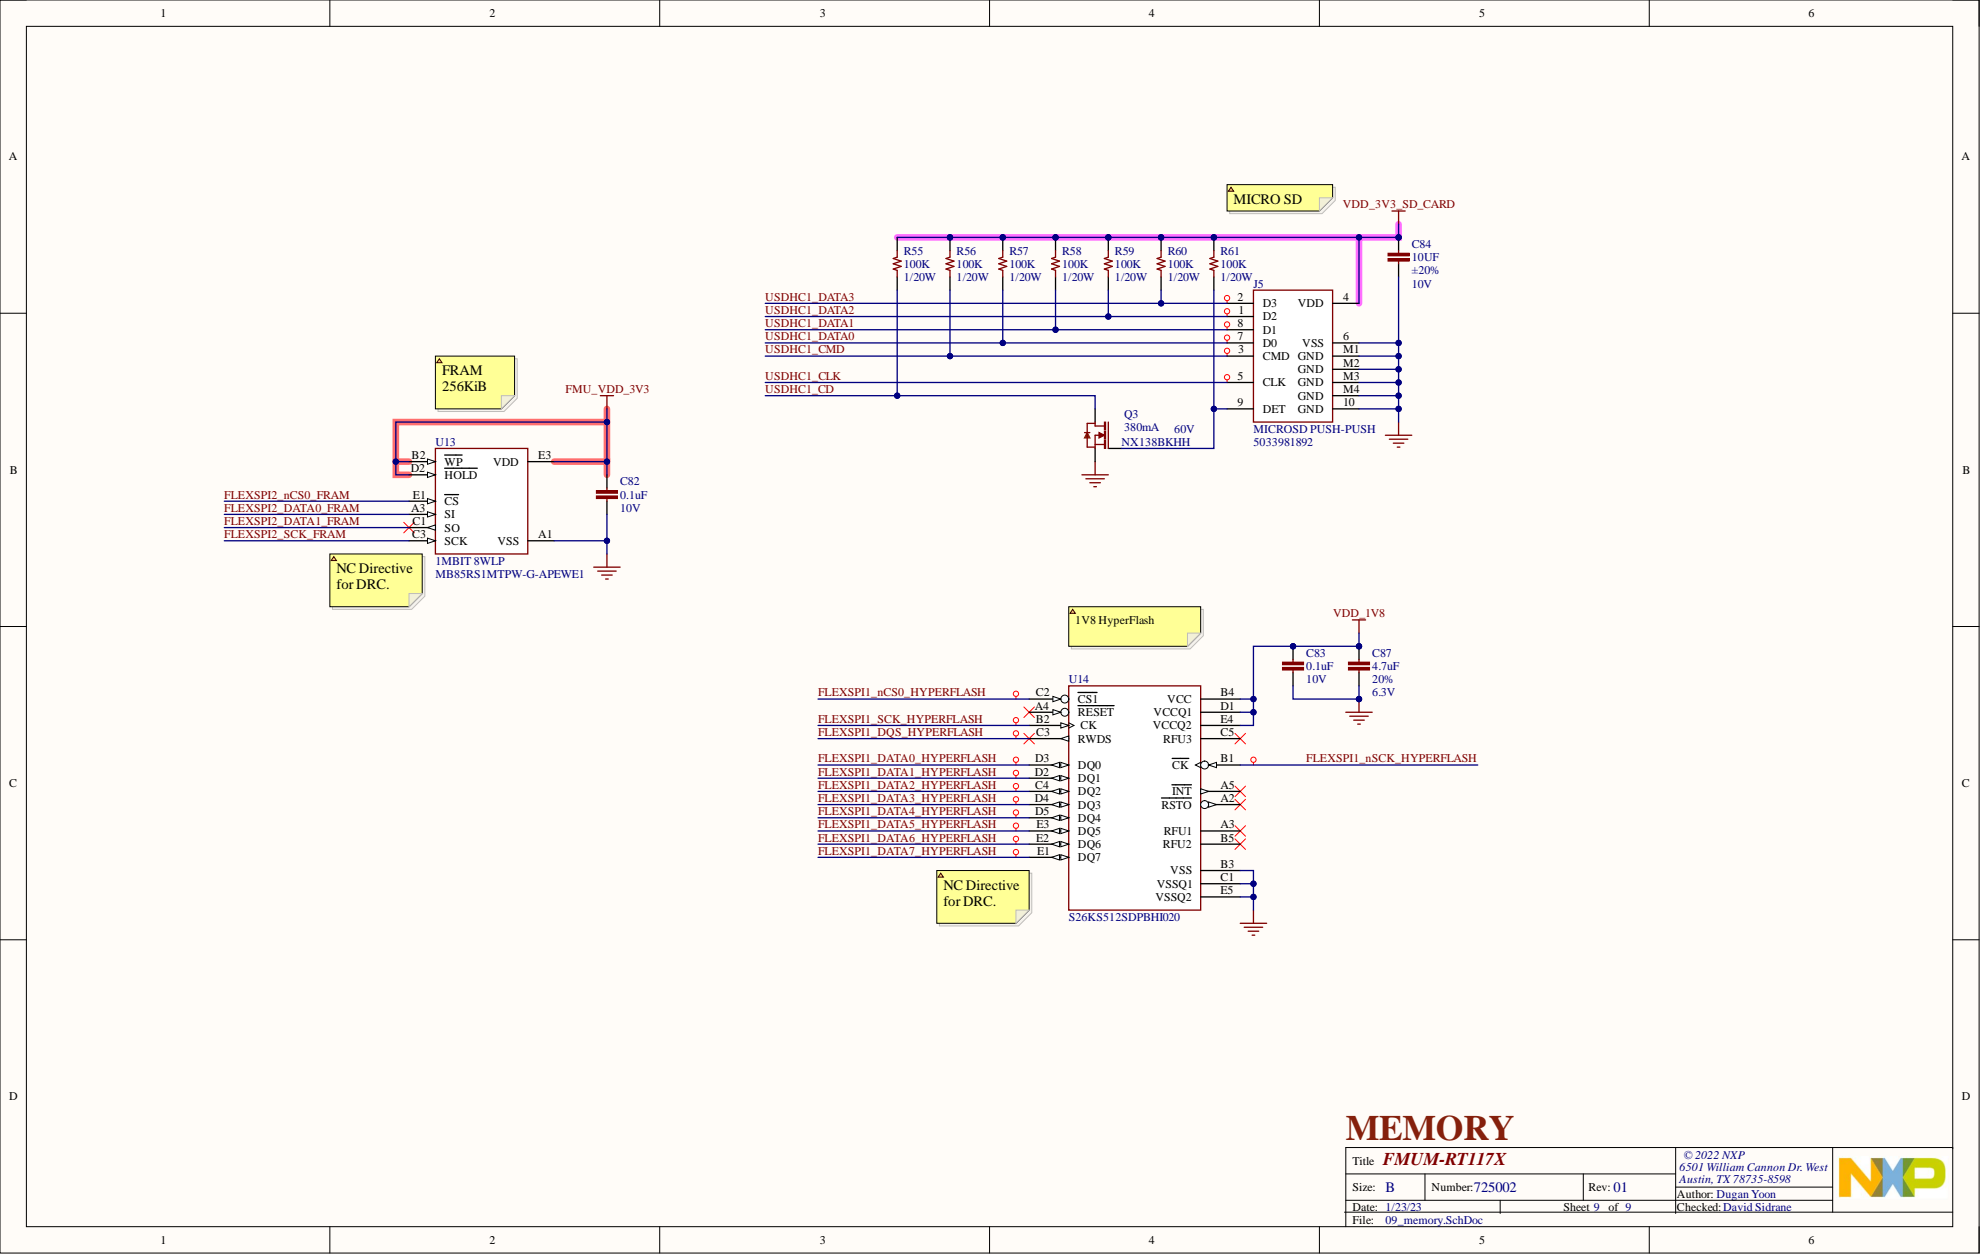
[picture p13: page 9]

6501 William Cannon Dr. West
Austin, TX 78735-8598

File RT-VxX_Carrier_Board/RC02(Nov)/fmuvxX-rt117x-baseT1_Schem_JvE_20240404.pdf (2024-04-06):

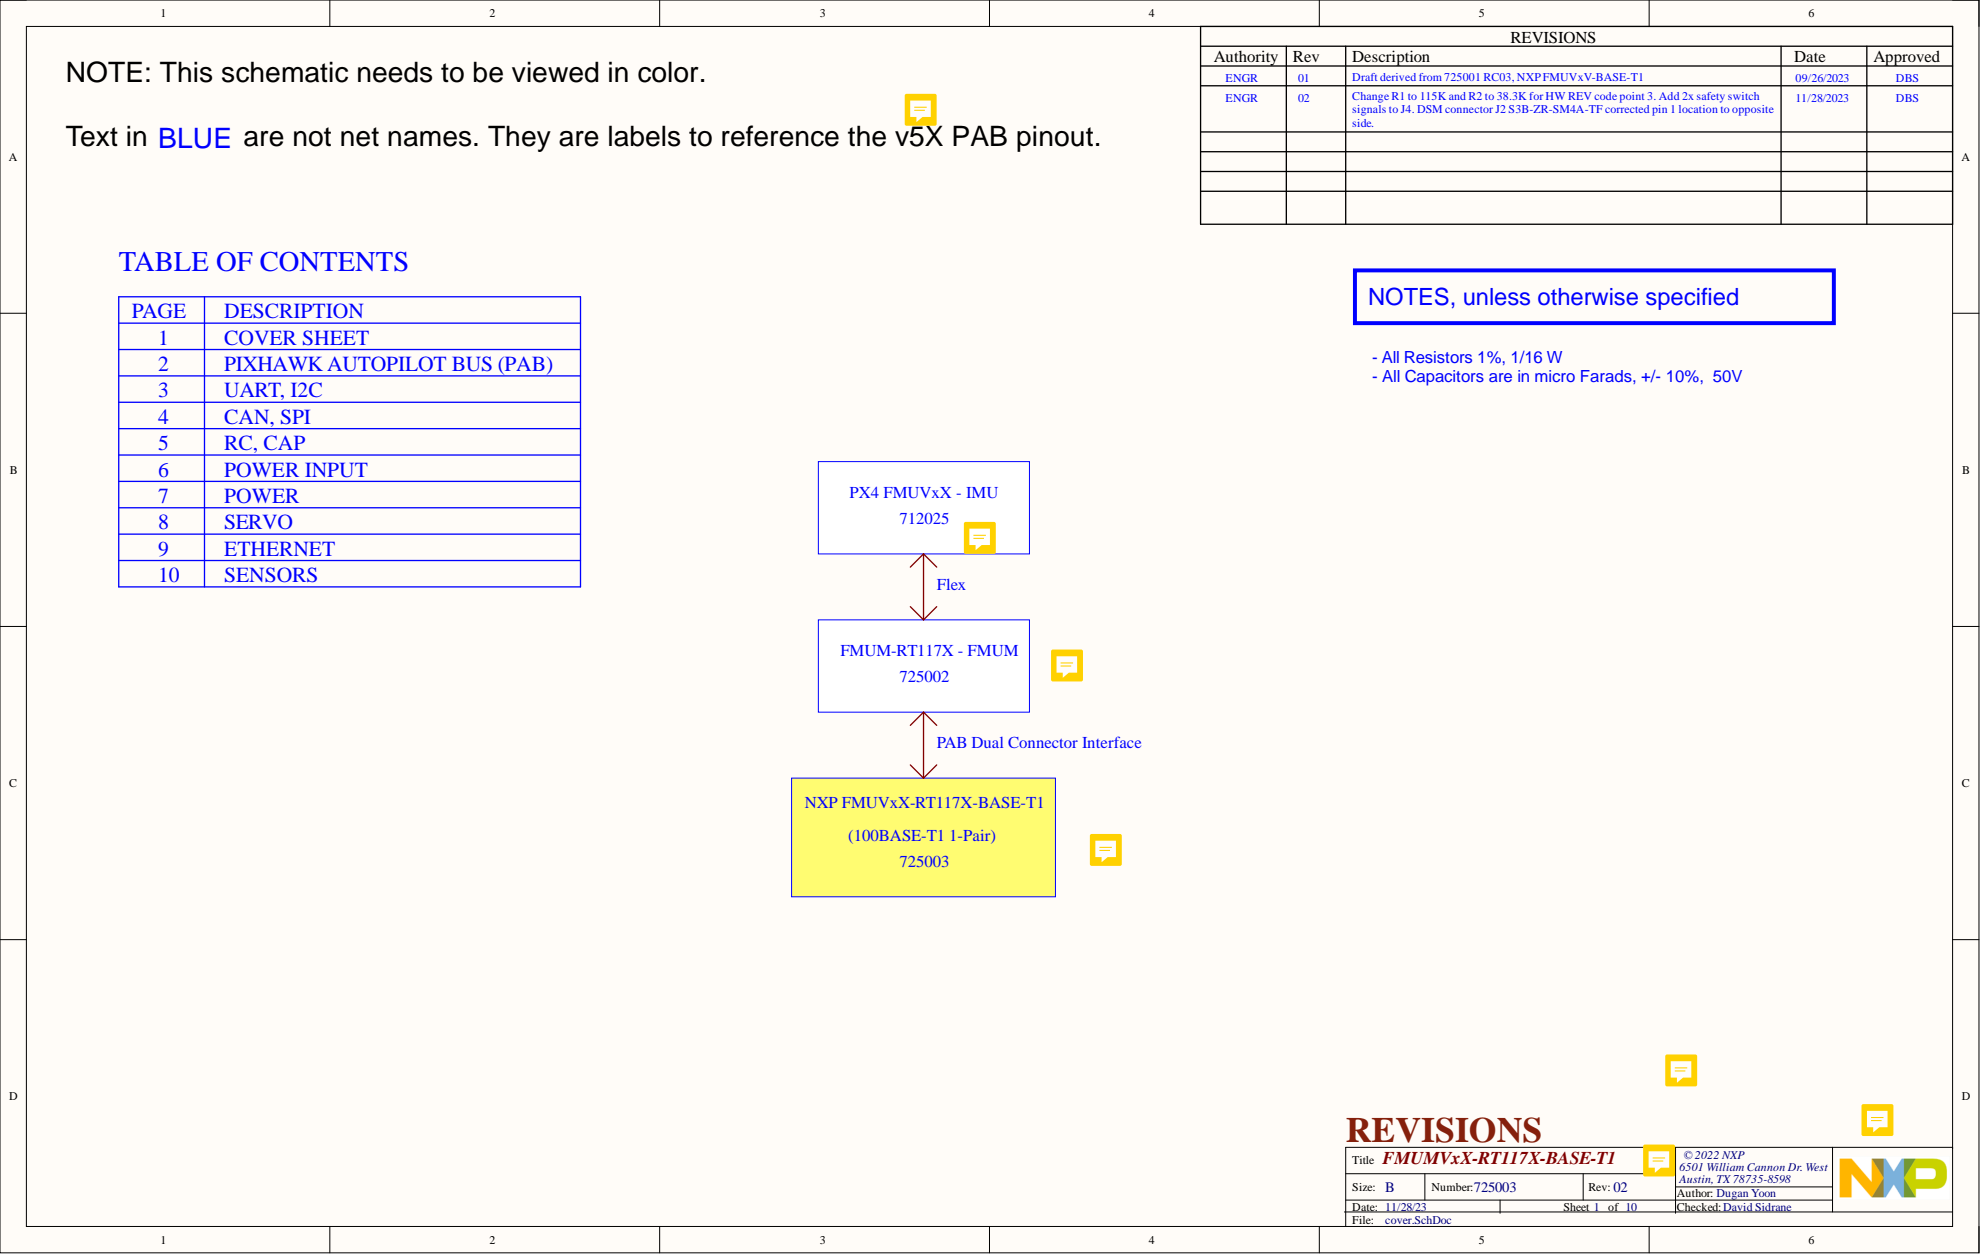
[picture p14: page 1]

Authority | Rev | Description | Date | Approved

NOTE: This schematic needs to be viewed in color.

ENGR | 01 | Draft derived from 725001 RC03, NXP FMUVxV-BASE-T1 | 09/26/2023 | DBS
ENGR | 02 | Change R1 to 115K and R2 to 38.3K for HW REV code point 3. Add 2x safety switch signals to J4. DSM connector J2 S3B-ZR-SM4A-TF corrected pin 1 location to opposite side. | 11/28/2023 | DBS

NOTES, unless otherwise specified

PAGE | DESCRIPTION
1 | COVER SHEET
2 | PIXHAWK AUTOPILOT BUS (PAB)
3 | UART, I2C
4 | CAN, SPI
5 | RC, CAP
6 | POWER INPUT
7 | POWER
8 | SERVO
9 | ETHERNET
10 | SENSORS

- All Resistors 1%, 1/16 W
- All Capacitors are in micro Farads, +/- 10%, 50V

PAB Dual Connector Interface

© 2022 NXP
6501 William Cannon Dr. West
Austin, TX 78735-8598

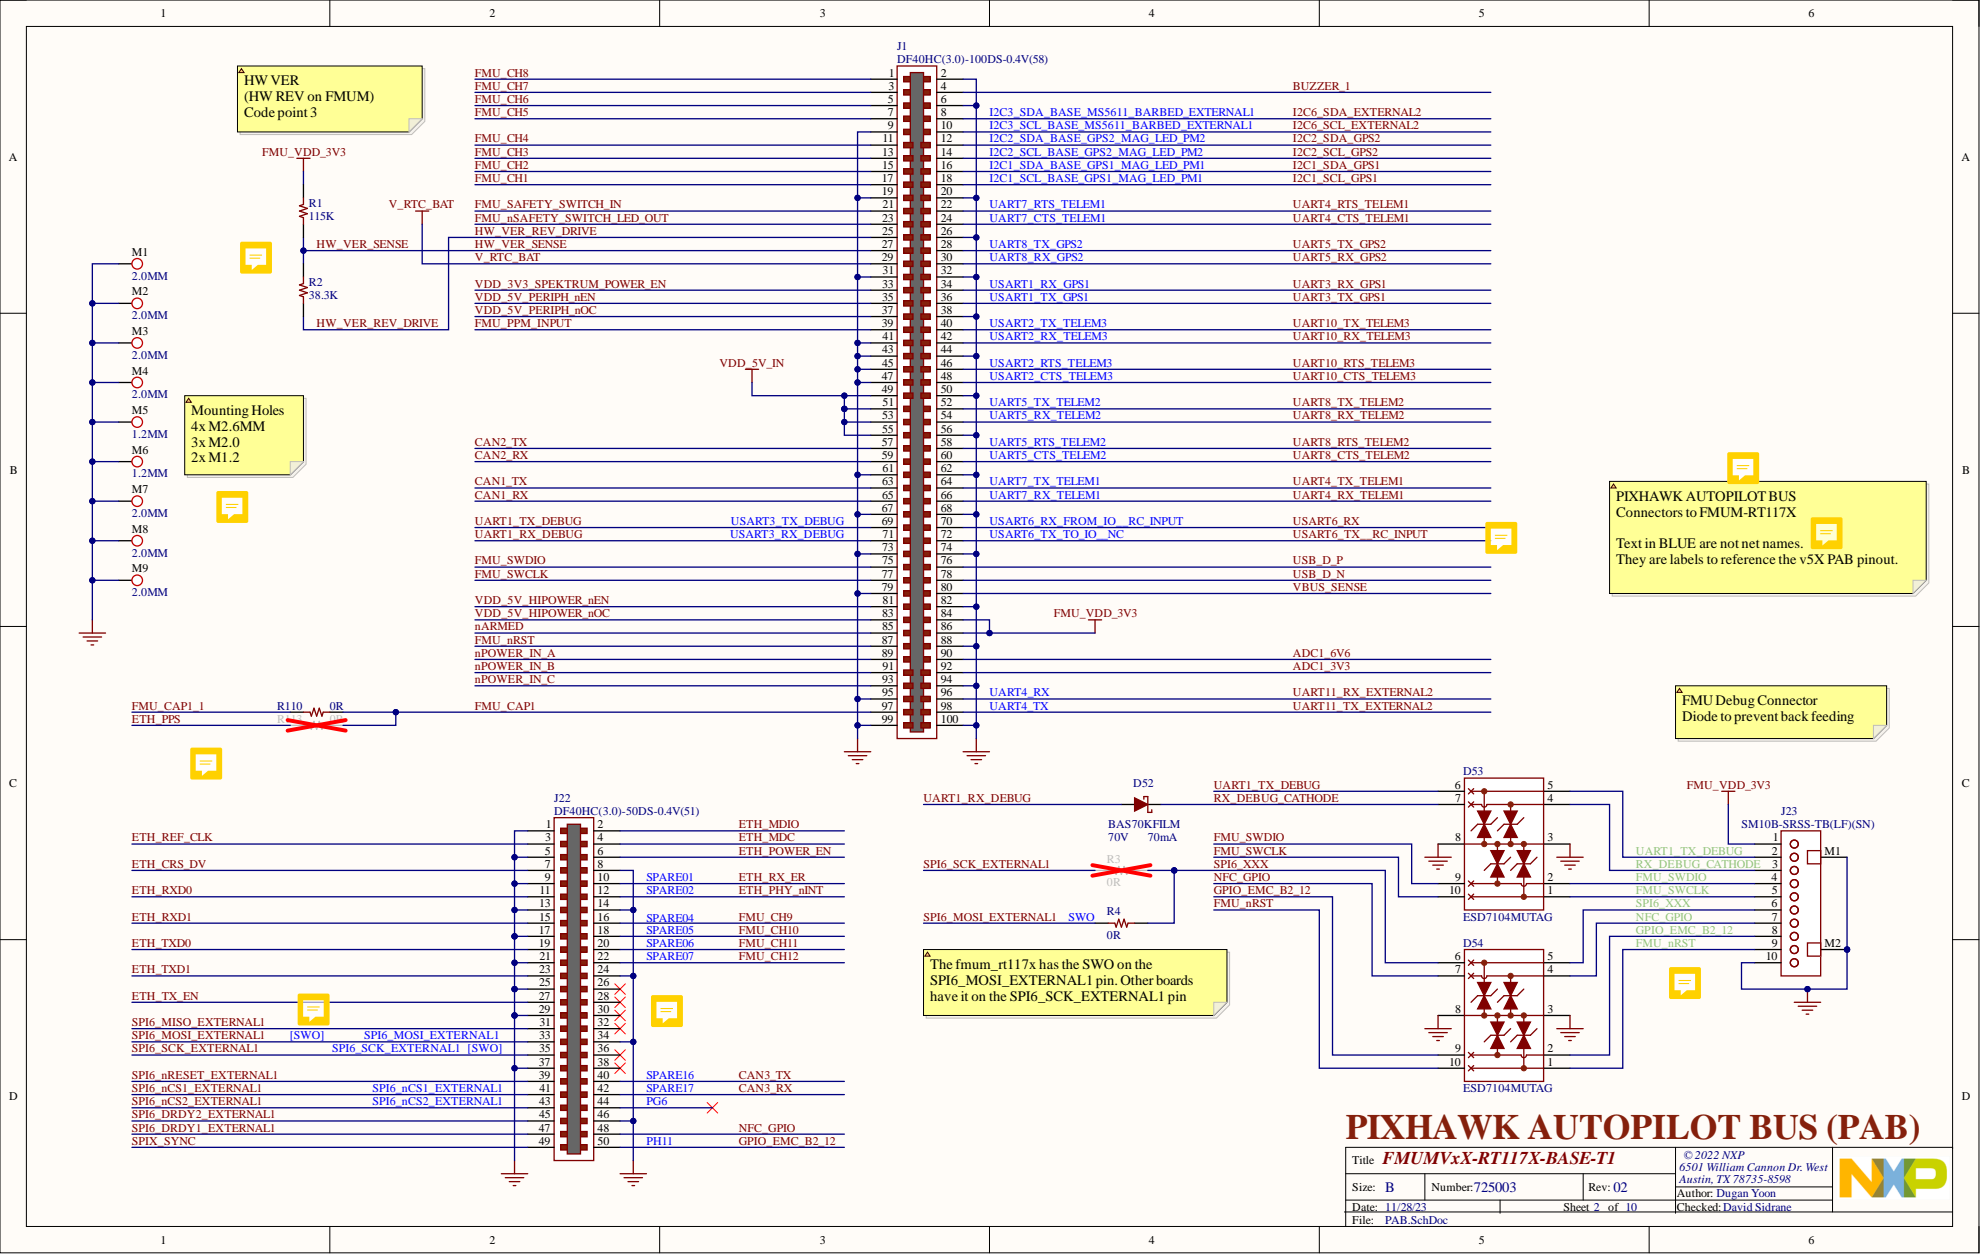
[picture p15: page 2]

5 3
5 5

0B-SRSS-TB(LF)(SN

PIXHAWK AUTOPILOT BUS (PAB)

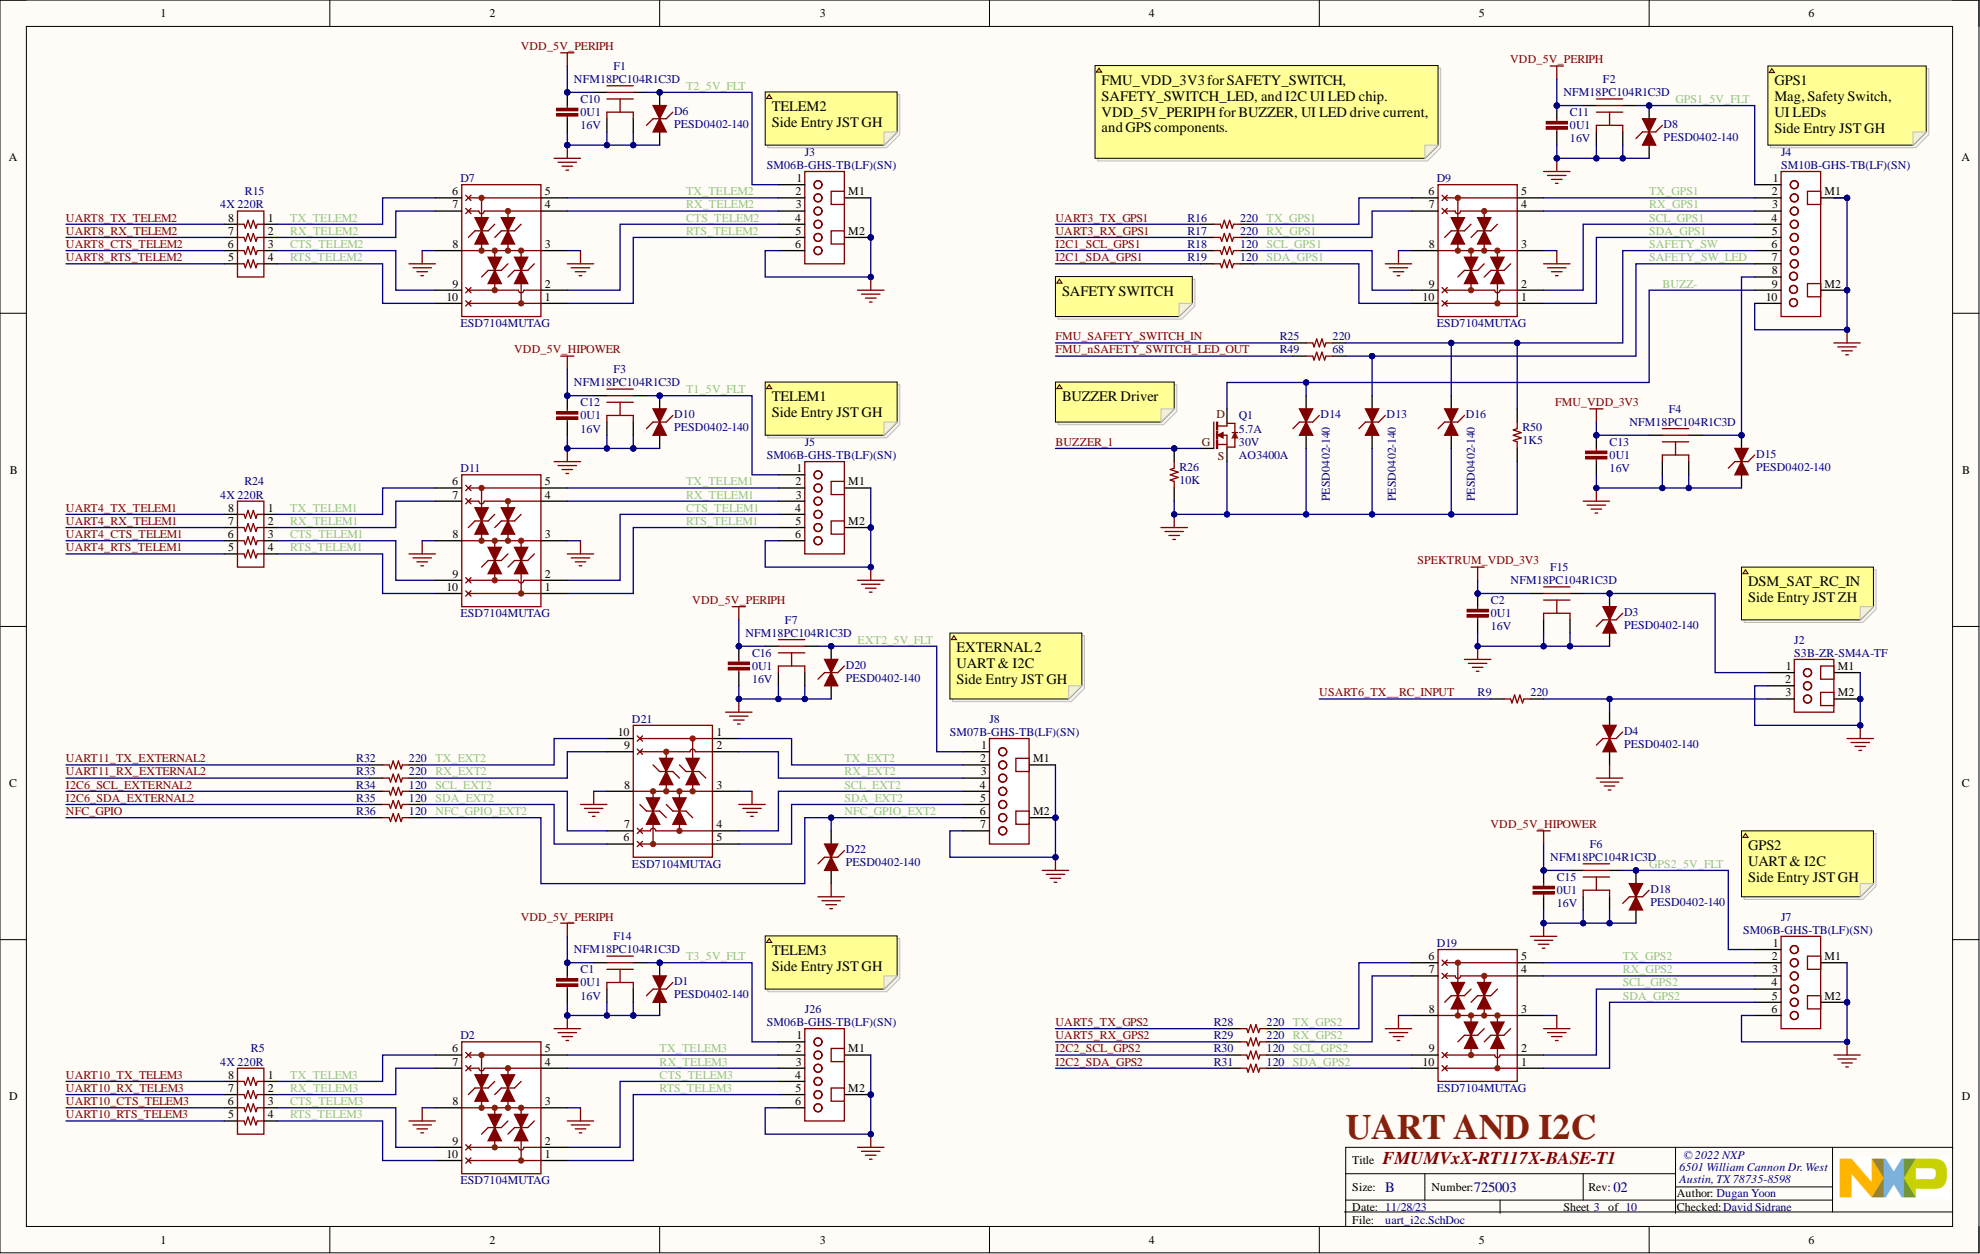
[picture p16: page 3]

FMU_VDD_3V3 for SAFETY_SWITCH,
SAFETY_SWITCH_LED, and I2C UI LED chip.
VDD_5V_PERIPH for BUZZER, UI LED drive current,
and GPS components.

GPS1
Mag, Safety Switch,
UI LEDs
Side Entry JST GH

D6 PESD0402-140

TELEM2

D8 PESD0402-140

TELEM1

TX_TELEM1 | 8 | CTS_TELEM1 4

DSM_SAT_RC_IN
Side Entry JST ZH

PESD0402-140

D20 PESD0402-140

SM07B-GHS-TB(LF)(SN)

3 | TX_EXT2 | 2

TELEM3


This note applies to all CAN interfaces: 120
Ohm termination is populated on FMU by
default. This is compatible with previous
FMUvXx implementations. Termination can
be defeated by removing 60R resistors.

SPI EXTERNAL1
Side Entry JST GH

MOSI_EXT1 4
CS1_EXT1 | 5
CS2_EXT1 nSYNC_EXT1 DRDY1_EXT1 | 6 7 8

DRDY2_EXT1 | 9

10


VDD

FMU_BOOTLOADER

ADIO
Capture andBootloader Request
Side Entry JST GH


Q 5 SIS9 0 3

USB OTG Full Speed

No Super Speed pins

USB OTG Side Entry JS


SENSOR 5V Power
250 mA PTC Resettable Fuse
Diode to prevent back feeding
EMI filter per port


AUX_PROT

FMU_CH12_PROT | 8 | 3
FMU_CH11_PROT
FMU_CH10_PROT | | 2

Top mounted connector:
Row C has Signals closer to Earth.

FMU_CH1_PROT | 1C

FMU and IO servo signals located on lower pins (GND on upper pins)
when FMU oriented right side up with connector on top, same as FMUV2.
If connector mounted on bottom orientaions should be flipped so that servo
signals remain closer to Earth and GND signals remain closer to the sky.

FMU_CH4_PROT | 8 | 3
FMU_CH3_PROT
FMU_CH2_PROT | | 2
FMU_CH1_PROT

Row B has Power signals
in middle row.

Row Ahas GND signals closer to Sky.

FMUV2 style servo header with 3-rows
VDD_SERVO must be externally applied

VDD_SERVO NOT USED FOR POWER
INPUT TO FLIGHT CONTROLLER!


xMII MODE | Pin CONFIG3 | Pin CONFIG4

RGMII-ID (RXC) | O | O

RGMII | O | H

RGMII-ID (both TXC/RXC) | O | L

RMII | H | O

RMII-clkmode | H | H

RMII-rev | H | L

MII | L | O

MII-rev | L | H

JTAG | L | L

MASTER | enabled | enabled | O | O

MASTER | disabled | enabled | O | H

SLAVE | enabled | enabled | O | L

SLAVE | disabled | enabled | H | O

MASTER | enabled | disabled | H | H

MASTER | disabled | disabled | H | L

SLAVE | disabled | disabled | L | H

reserved | reserved | reserved | L | L

SM02B-GHS-TB(LF)(SN)

TDI/GPIO1 18

RX_ER/GPIO2/TDO/CONFIG1 19

TXC 29

TXD0 31
TXD1 32
TXD2/GPIO10 33

Config3 = fixed high (RMII mode)


D55 PESD0402-140

SM04B-GHS-TB(LF)(SN)

SM02B-GHS-TB(LF)(SN)

Secure Element Onboard
Address=0x48
Text in BLUE are not net names.
They are labels to reference the v5X pinout.




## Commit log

2022-09-10 initial upload
    open design of FMUMRT6
    Latest is RC02 and RC04
    [01_cover.SchDoc, 02_PAB.SchDoc, 03_io_mcu.SchDoc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]
2023-07-17 moving directories
    [01_cover.SchDoc, 02_PAB.SchDoc, 03_io_mcu.SchDoc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]
2023-07-17 Add FMUM RT117x design files and schematic
    Schematic is embedded in the ZIP files.
    NOTE this board revision is prototype only. We will make some changes before production. Please check in with the Mobile Robotics team for any updates.
2023-11-30 These are RC02 revised after review
    The RC input should be corrected. Also resistor values adjusted. And GPS signals that were unconnected are corrected.
2023-11-30 Create changes.txt
    short list of minor updates to the board.
2023-11-30 re-upload FMUM files
    Original upload seems to have disappeared
    [Naming_MR-VMU-RT1176.xlsx]
2024-04-06 Add files via upload
    This PDF is the marked up schematic to align with AS-BUILT units.
    Please refer to the notes and comments embedded in the PDF.
    These will be incorporated in the final published design files.
    There are some parts such as a ultracap/battery that have been identified as difficult to get. As a result the final design may see small footprint changes to correctly adapt to allow a replacement to be placed on the board. There should NOT be any significant layout/trace changes on the board.
2024-06-20 Version updated June 2024
    including replacement options for obsolete supercap.
    - primary lithium coin cell on fmuvxX base board
